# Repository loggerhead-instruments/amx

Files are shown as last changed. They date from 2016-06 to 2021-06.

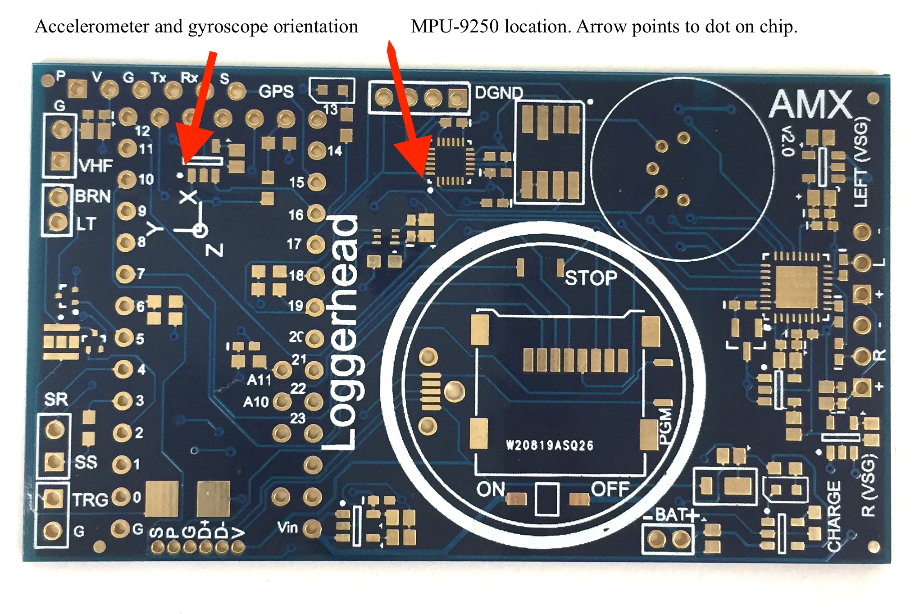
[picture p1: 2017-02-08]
AMXboard_orientation.jpg

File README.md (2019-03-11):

# AMX
AMX is an arduino-compatible audio and motion datalogger board (designed for Teensy 3.x)

More information is at http://loggerhead.com

### Converting AMX to wav and csv files:
- Use AMX2WAV https://github.com/loggerhead-instruments/amx/tree/master/VisualStudio/AMX2WAV/x64/Release

### Files:
- amx: Main control and sensor recording
- cmd.pde: Reads recording settings from a script file
- ISL29125: RGB light sensor interface
- MPU9250: Invensense IMU sensor interface
- wav.h: wav header
- rms: rms calculation

### Sensors:
- Accelerometer, Gyroscope, Magnetometer (MPU9250)
- Pressure/Temperature (MS5803)
- RGB light (ISL29125)
- Burn wire release: controls a FET switch to ground which can be used to corrode a stainless steel wire in seawater

### Software supports:
- duty cycle recording
- display
- button input for recording setup
- writing to microSD

## Updating Firmware

1.	Install Teensyduino from https://www.pjrc.com/teensy/loader.html
2.	Get latest hex file from appropriate repository
	https://github.com/loggerhead-instruments/amx/tree/master/hex
	To save file, right click on the filename and choose 'Save link as'
3.	Connect microUSB cable to small board on device
4.	Run the Teensy Loader program.
5.	From File Menu, select Open HEX File
6.  Turn on power to board
7.	Press the PGM button on the board next to the microSD slot, or from Operation menu, select Program (you may have to turn off automatic mode).

To check whether the firmware has been updated, collect some data, and check the log files for the version date of the firmware.

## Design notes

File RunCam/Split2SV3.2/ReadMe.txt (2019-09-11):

Firmware Upgrade
1. After downloading the firmware, unzip the downloaded file, find the Split2S.BRN file and copy it to the root directory of the microSD card. The firmware name should be confirmed as RCSplit.BRN.
2. Disconnect from the computer, powering the camera via the mobile charger. And then turn on the RUNCAM Split2S with the micro SD card inserted. The camera will automatically update the firmware.
3. Orange light blinks slowly while firmware is upgrading.
4. After 1 minute, the camera will automatically shut down,upgrade has completed.

======================================================================================
New features of RunCam Split2S V3.2.0
1. Fixed bug:The camera does not turn on properly when the camera board is too hot.

======================================================================================
New features of RunCam Split2S V3.1.0
1. Optimize image quality.

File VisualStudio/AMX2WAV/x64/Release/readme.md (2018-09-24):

Downloading AMX.zip

Click on AMX.zip to open new page, then click Download button.
You will have to choose Run Anyway to run.

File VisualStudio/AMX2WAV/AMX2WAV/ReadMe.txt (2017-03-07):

================================================================================
    MICROSOFT FOUNDATION CLASS LIBRARY : AMX2WAV Project Overview
===============================================================================

The application wizard has created this AMX2WAV application for
you.  This application not only demonstrates the basics of using the Microsoft
Foundation Classes but is also a starting point for writing your application.

This file contains a summary of what you will find in each of the files that
make up your AMX2WAV application.

AMX2WAV.vcxproj
    This is the main project file for VC++ projects generated using an application wizard.
    It contains information about the version of Visual C++ that generated the file, and
    information about the platforms, configurations, and project features selected with the
    application wizard.

AMX2WAV.vcxproj.filters
    This is the filters file for VC++ projects generated using an Application Wizard. 
    It contains information about the assciation between the files in your project 
    and the filters. This association is used in the IDE to show grouping of files with
    similar extensions under a specific node (for e.g. ".cpp" files are associated with the
    "Source Files" filter).

AMX2WAV.h
    This is the main header file for the application.  It includes other
    project specific headers (including Resource.h) and declares the
    CAMX2WAVApp application class.

AMX2WAV.cpp
    This is the main application source file that contains the application
    class CAMX2WAVApp.

AMX2WAV.rc
    This is a listing of all of the Microsoft Windows resources that the
    program uses.  It includes the icons, bitmaps, and cursors that are stored
    in the RES subdirectory.  This file can be directly edited in Microsoft
    Visual C++. Your project resources are in 1033.

res\AMX2WAV.ico
    This is an icon file, which is used as the application's icon.  This
    icon is included by the main resource file AMX2WAV.rc.

res\AMX2WAV.rc2
    This file contains resources that are not edited by Microsoft
    Visual C++. You should place all resources not editable by
    the resource editor in this file.

/////////////////////////////////////////////////////////////////////////////

The application wizard creates one dialog class:

AMX2WAVDlg.h, AMX2WAVDlg.cpp - the dialog
    These files contain your CAMX2WAVDlg class.  This class defines
    the behavior of your application's main dialog.  The dialog's template is
    in AMX2WAV.rc, which can be edited in Microsoft Visual C++.

/////////////////////////////////////////////////////////////////////////////

Help Support:

hlp\AMX2WAV.hhp
    This file is a help project file. It contains the data needed to
    compile the help files into a .chm file.

hlp\AMX2WAV.hhc
    This file lists the contents of the help project.

hlp\AMX2WAV.hhk
    This file contains an index of the help topics.

hlp\afxcore.htm
    This file contains the standard help topics for standard MFC
    commands and screen objects. Add your own help topics to this file.

makehtmlhelp.bat
    This file is used by the build system to compile the help files.

hlp\Images\*.gif
    These are bitmap files required by the standard help file topics for
    Microsoft Foundation Class Library standard commands.

/////////////////////////////////////////////////////////////////////////////

Other Features:

ActiveX Controls
    The application includes support to use ActiveX controls.

/////////////////////////////////////////////////////////////////////////////

Other standard files:

StdAfx.h, StdAfx.cpp
    These files are used to build a precompiled header (PCH) file
    named AMX2WAV.pch and a precompiled types file named StdAfx.obj.

Resource.h
    This is the standard header file, which defines new resource IDs.
    Microsoft Visual C++ reads and updates this file.

AMX2WAV.manifest
	Application manifest files are used by Windows XP to describe an applications
	dependency on specific versions of Side-by-Side assemblies. The loader uses this
	information to load the appropriate assembly from the assembly cache or private
	from the application. The Application manifest  maybe included for redistribution
	as an external .manifest file that is installed in the same folder as the application
	executable or it may be included in the executable in the form of a resource.
/////////////////////////////////////////////////////////////////////////////

Other notes:

The application wizard uses "TODO:" to indicate parts of the source code you
should add to or customize.

If your application uses MFC in a shared DLL, you will need
to redistribute the MFC DLLs. If your application is in a language
other than the operating system's locale, you will also have to
redistribute the corresponding localized resources MFC100XXX.DLL.
For more information on both of these topics, please see the section on
redistributing Visual C++ applications in MSDN documentation.

/////////////////////////////////////////////////////////////////////////////

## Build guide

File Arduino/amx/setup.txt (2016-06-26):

// Example setup.txt file

// Set time on power
TM 2016-06-06 12:00:00

// Enable IMU 100 Hz
IM 100.0

// MS Pressure
MP

// RGB light sensor
LS

// Rec duration
RD 30

// Rec interval
RI 30

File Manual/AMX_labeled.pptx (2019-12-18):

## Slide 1

microUSB

Pressure/Temperature

Hydrophone

Tag orientation for heading calculation used by amxEuler.m

East

Light sensor

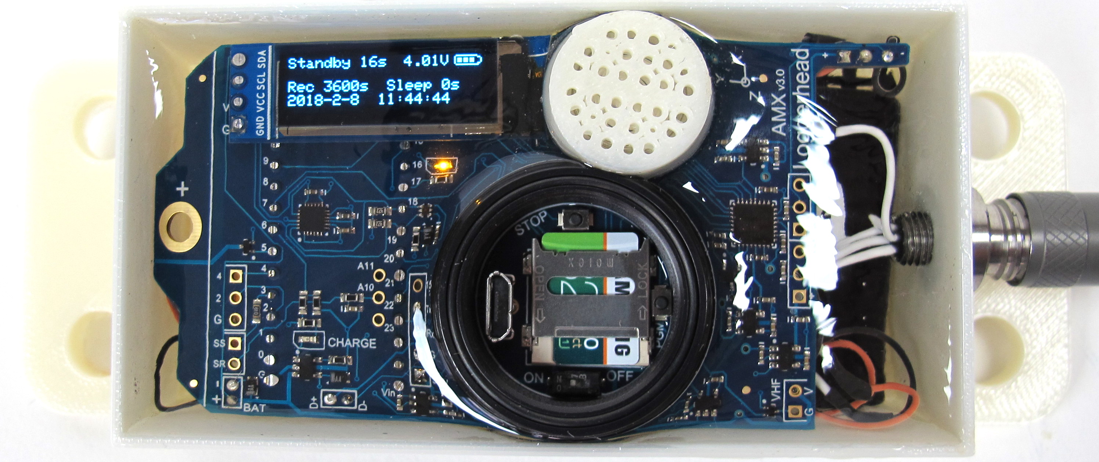
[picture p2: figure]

Motion sensor

North

Charge LED
(turns off when charged)

microUSB

On/Off Switch

microSD card
Slide and flip up to remove

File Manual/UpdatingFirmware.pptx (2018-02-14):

## Updating Firmware

1. Download Teensy loader program from: https://www.pjrc.com/teensy/loader.html
2. Run Teensy Loader
3. File Menu: Open Hex
4. Choose amx.ino.hex (It may say file is too big...ignore)
5. Remove microSD card from AMX
6. Connect microUSB cable to the AMX board
7. Turn AMX power switch to on
8. Short the two pads to force reprogramming. This should cause the firmware to upload.

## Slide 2

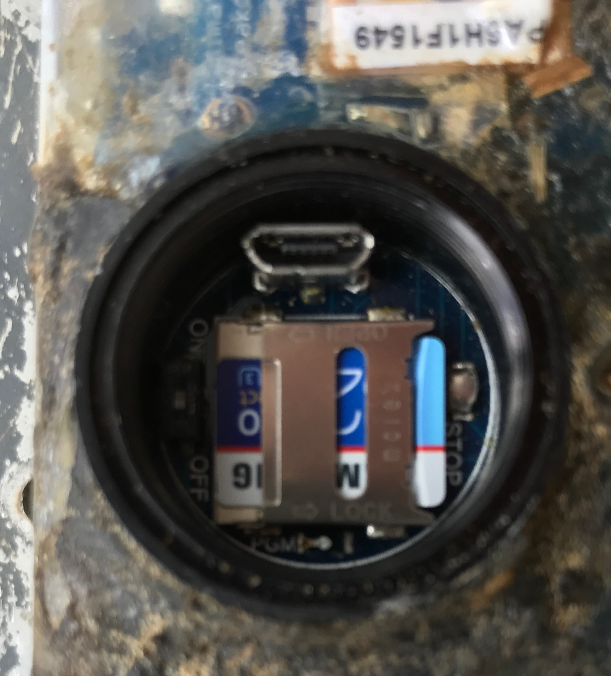
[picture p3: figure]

Connect these two pads with a wire to force reprogramming

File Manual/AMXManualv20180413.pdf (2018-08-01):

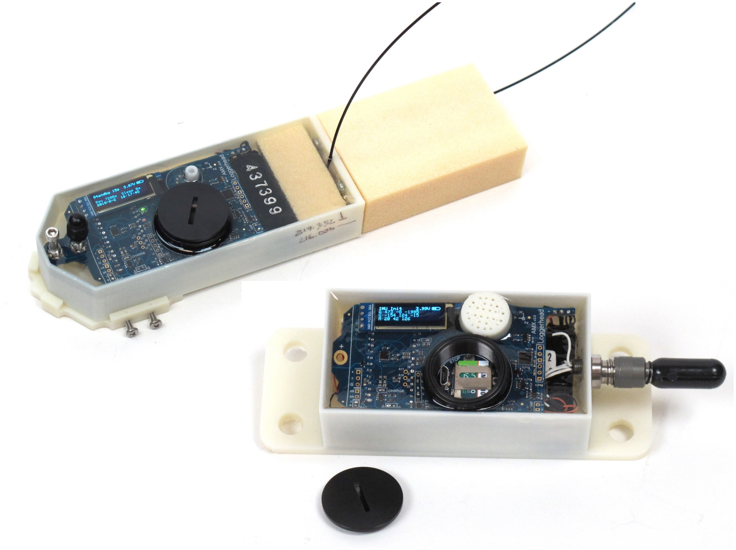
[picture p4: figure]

AMX Manual | 1

# AMX MANUAL

## Audio-Motion Datalogging Tag

Updated 13 April 2018

www.loggerhead.com

## Overview

Hardware

AMX is a multi-sensor datalogger designed for collecting acoustic and motion data from tagged animals and underwater platforms.

Sensors:

- HTI hydrophone: 44.1 kHz
- Accelerometer, Gyroscope, Magnetometer (MPU9250): 100 Hz
- Pressure/Temperature (MS5837 or Keller PA7LD): 1 Hz
- RGB light level (ISL29125): 1 Hz
- Burn wire release: controls a FET switch to ground which can be used to corrode a stainless steel wire in seawater
- Optional camera
- Optional sound playback
- Optional VHF board to aid in recovery

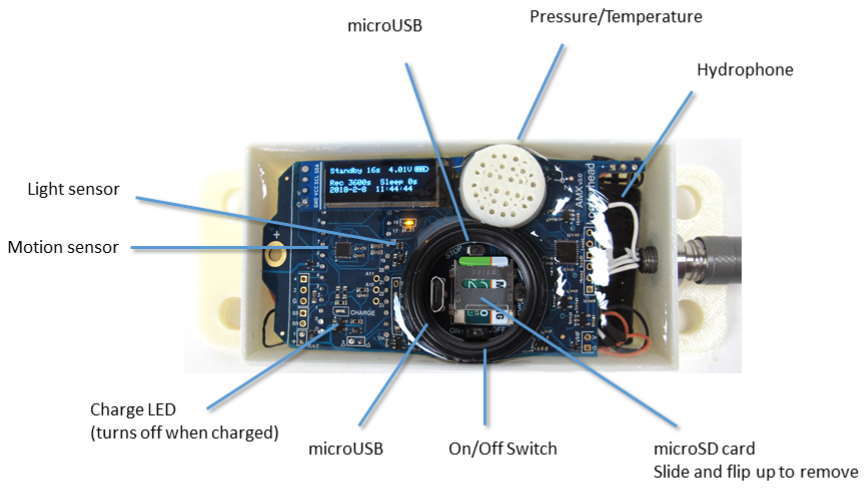
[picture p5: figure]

Software
AMX stores data as .amx binary files. These files can be converted to multi-channel wav files with one for each sensor using AMX2WAV (Windows 10).

https://github.com/loggerhead-instruments/amx/blob/master/AMXsetup.zip

MATLAB code for importing files is available at: https://github.com/loggerhead-instruments/amx/tree/master/MATLAB

All firmware is open source and is available at GitHub: https://github.com/loggerhead-instruments/amx

## Setting up AMX for Deployment

Step 1. Prepare microSD card. Create setup.txt file if setting the time, using the burn wires, or changing default settings. Be sure to safely eject the card before removing from computer.
Step 2. O-rings. Clean and grease o-rings with silicone grease, and insert into the groove on the ring. The o-ring is a 1 x 25 mm 70 Shore A Buna N o-ring. They are McMaster-Carr part number 9262K624.

The o-rings need to be removed and cleaned for each use. If there are nicks in an o-ring DO NOT use it.

Step 3. Turn camera switch on if using camera.
Step 4. Turn on tag power switch and monitor display (see below) during startup.
Step 5. Close lid. Lids should be closed securely using a coin. It should be more than hand-tight.

## Startup Sequence

After powering on AMX the following operations will be performed.

Tag power up sequence | Display | LED pattern
1. Tag turned on | | On for 4 seconds
2. IMU initialization | IMU Init Raw: A(ccelerometer) G(yroscope) M(agnetometer) Calculated: P(itch) R(oll) Y(aw) | Off
3. Light sensor initialization | Light Init R(ed) G(reen) B(lue) | Off
4. Pressure/Temp Sensor Initialization | Pressure (mBar) Depth (m) Temperature (C) | Off
5. Standby to start | Count down Burn date and time *B (if set) Record file duration Sleep duration Current date and time | Solid On
6. Delay Start | If delayed starts | Blink once every 20 seconds
7. Start recording | Turns Off | Blink once per second for 1 hour. After 1 hour the LED will be turned off. The tag will still be recording.

setup.txt Commands
All commands are optional. Default column lists values if no setting in setup.txt file. The sample rates of the pressure and light sensors are fixed.
Command | Function | Default | Example | Setup.txt example
TM | Sets time Time is given as: YY-MM-DD HH:MM:SS If a value is less than 10, it should be written with a leading 0. E.g. 5 should be 05 There must be a space between the DD and HH. | Current time, unless battery exhausted. | Set time to 2017-July-02 04:00:00 when tag powered on | TM 17-07-02 04:00:00
DS | Delay Start (HH:MM) | 00:00 | Delay start for 2 hours | DS 02:00
RD | Record duration (s) | 3600 | Record 600 second files | RD 600
RI | Record interval (s) | 0 | Sleep 240 seconds between files | RI 240
SG | Hydrophone system gain. See table for dB gains associated with different settings. | 4 | Set gain to setting ‘10’, which corresponds to 11.1 dB gain | SG 10
ND | Remove DC from audio. Turning on increases electrical noise | Off | Turn on feature to remove DC from audio | ND
AG | Accelerometer full scale (2, 4, 8, or 16 g) | 16 | Set accelerometer to +/- 8 g full scale | AG 8
IM | IMU sample rate | 100 | Set IMU sample rate to 50 Hz | IM 50

Burn Wire Settings: *Only one burn wire command will be active (the last one in the script).

BW | Burn at YY-MM-DD HH:MM:SS | No burn | Burn at 2017-July-03 20:00:00 | BW 17-07-03 20:00:00
BM | Burn in Minutes from start | No burn | Burn 60 minutes after start | BM 60

Hydrophone Calibration
HC | Hydrophone
sensitivity stored to
file
-180 | Change
hydrophone
sensitivity to -
170 dBV/uPa

HC -170

Playback Commands
Command | Function | Default | Example | Setup.txt example
PF | Number of playback files | 0 | 5 wav files | PF 5
PI | Minimum playback interval (seconds) | 120 | Playbacks separated by at least 500 s | PI 500
PD | Longest file for playback (seconds). Used to power down playback board. | 30 | Longest playback is 15 seconds | PD 15
PT | Playback depth threshold (m). Tag must go deeper than this depth to trigger threshold | 10.0 | Tag must go deeper than 100.0 m before an ascent trigger can trigger playback | PT 100.0
PA | Ascent depth trigger. After exceed depth threshold, the maximum depth is determined. When the tag ascends this amount, playback is triggered | 5.0 | Trigger playback when ascend 20.0 m above the deepest depth | PA 20.0
PR | Reset depth (m). Tag needs to come back above this depth before next playback | 2.0 | Tag must ascend through 5.0 m before another playback can be | PR 5.0

| can happen. | | queued
PM | Max number of playbacks | 20 | Maximum of 10 playbacks | PM 10
SD | Simulate depth profile to test playback. | Off | Turn on simulation of depth (NEVER USE THIS FOR AN ACTUAL DEPLOYMENT) | SD

Debugging
DI
| Print debug information to serial port | Off | Turn on debug information | DI

## Charging

The AMX incorporates rechargeable lithium polymer batteries. Connect the microUSB cable to the AMX and plug into a computer to charge. The red LED will come on to indicate the batteries are charging. The red LED will go out when the batteries are fully charged. It will take approximately 10 hours to fully charge the double-battery version of AMX.

## Power

Tags can be supplied with either 1 or 2 lithium polymer rechargeable batteries (2500 mAh).

Run time for tags without cameras
Run time with 1 battery is approximately 1.5 days.
Run time with 2 batteries is approximately 3.0 days.

Tags with cameras are custom designed to have the needed battery power to achieve user-specified recording durations.

If the battery voltage drops below 3.7 V the camera will be powered down to save power. If the voltage drops below 3.0 V, audio files will stop being recorded.

## Setting Time

The time is set through the setup.txt file. When creating the setup.txt file to set the time, pick a time in the near future. Eject the card, put it in the tag, and then wait until the time you had put in the setup.txt file occurs, and then turn the tag on. The clock will reset to the time in the setup.txt file.

Note that the TM line in setup.txt will be commented out after the time is set, to avoid the time being reset incorrectly if the tag is turned off and on.

## Burn Wire

A burn wire is a corrodible stainless steel wire that can be used to release the AMX from a platform or release suction from suction cups. The recommended wire is from McMaster-Carr (302/304 stainless steel wire 0.01” diameter). https://www.mcmaster.com/ - 6517k61/=17yvpwx

If using suction cups, after attaching the burn wire, coat the base of burn wire where it attaches to the post with nail polish so that it corrodes preferentially at the point of attachment to the suction cups.

The timing of the start of the burn is controlled by a setting in the setup.txt file located on the microSD card in the AMX. Note that the microSD card in the camera is separate, and is only used to store camera data (i.e. don’t put the setup.txt file on the camera card)

There are two ways to set when the burn wire will start, either by specifying a date and time (BW command) or by specifying the number of minutes after the start of recording to start burning (BM command). The format for the two commands is below. Only one of these commands should be used. Pay attention to the exact format of the command. EACH DATE AND TIME VALUE MUST BE TWO CHARACTERS.

BW YY-MM-DD HH:MM:SS
BM minutes

## The BM command is the safest, because it will still work even if the time on the real-time clock is

wrong.

After the burn wire is triggered the VHF beacon will be turned on. When the power gets low, the AMX will go into sleep mode. The green LED will flash 10x once every 2 minutes in sleep mode.

## VHF

If your AMX has the optional VHF, it will turn on based on the depth or the status of the burn wire. If the depth is deeper than 1.0 m, the VHF will turn off. The
VHF will be turned on and stay on after the burn wire is triggered. The VHF signal is very strong, and is picked up as electromagnetic interference on the hydrophone. This is normal, if not annoying.

## Depth Sensors and Maximum Depth

The AMX is equipped with one of two types of pressure sensors, each of which has a maximum depth that it can sustain. If the tag could go deeper than 300 m, the air void where the microSD card is located should be filled with mineral oil. Mineral oil is non-conductive, and will keep the cap from imploding if the tag goes deeper than 300 m.

TE Connectivity (Measurement Specialities)
2 Bar (20 m max depth)
30 Bar (300 m max depth)

Keller
200 Bar (2000 m max depth) Or other sensor as specified.

## HTI Hydrophone Specifications

The AMX uses a hydrophone manufactured by High-Tech Inc. The sensitivity of the hydrophone will be on a specification sheet included with the shipment.

The A/D converter gain can be changed through the setup.txt file. The default is setting 4. The setting can be changed with SG command in setup.txt. The actual setting that was used is stored to the log.txt file.

Setting | Clip Level (peak-peak) | Clip Level (peak) | Gain (dB)
0 | 3.12 | 1.56 | -3.9
1 | 2.63 | 1.315 | -2.4
2 | 2.22 | 1.11 | -0.9
3 | 1.87 | 0.935 | 0.6
4 | 1.58 | 0.79 | 2.0
5 | 1.33 | 0.665 | 3.5
6 | 1.11 | 0.555 | 5.1
7 | 0.94 | 0.47 | 6.6
8 | 0.79 | 0.395 | 8.1
9 | 0.67 | 0.335 | 9.5
10 | 0.56 | 0.28 | 11.1
11 | 0.48 | 0.24 | 12.4
12 | 0.4 | 0.2 | 14.0
13 | 0.34 | 0.17 | 15.4
14 | 0.29 | 0.145 | 16.8
15 | 0.24 | 0.12 | 18.4

## AMX File Conversion Software

The AMX files are binary encoded. AMX2WAV is a Windows 10 software program that will convert the AMX files to a wav file. Each converted wav file stores the data from one of the sensors (e.g. hydrophone audio, 3D IMU, RGB light sensor).

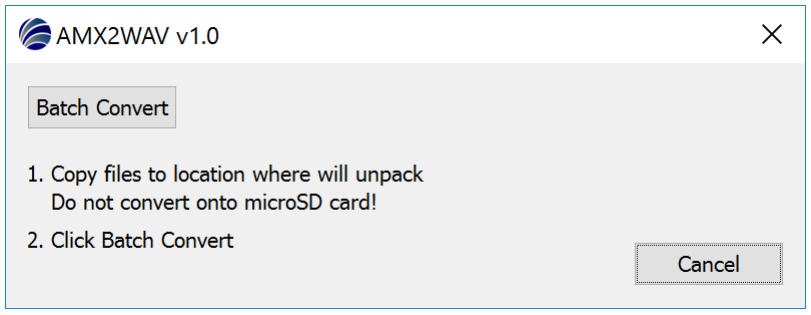
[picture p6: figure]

1. Copy the files from the microSD card to a new location.
2. Click Batch Convert and select a file from the folder where you copied the data to convert.
3. A new folder labeled wav will be created with the converted files.

Playback Operation

The AMX uses the Adafruit Audio FX board with serial interface: https://learn.adafruit.com/adafruit-audio-fx-sound-board/overview

File Configuration
- Files are uploaded to the playback board through a USB connection, and then the drive ejected to make sure they all copied. The copy rate IS VERY SLOW. BE PATIENT!
- Files should be named: T00.wav, T01.wav, T02.wav, T03.wav
- Maximum of 16 MB total for all files
- Files will be triggered in sequence, first 0, then 1, then 2, ….

Setup.txt File
The setup.txt file is placed on the microSD card of the AMX board to control playback operation.
Each command should go on its own line with a space before the value, if the command takes a value.
A double slash // can be used to put in a short comment.

Principles of playback triggering
1. A depth threshold (PT) must be exceeded to prime a playback.
2. Once the depth threshold is exceeded, a playback will occur when the depth goes shallower than the ascent depth trigger (PA).
3. For another playback to occur, the following must be satisfied:
1. the tag went shallower than the reset depth (PR). This is to prevent multiple playbacks if the animal goes up and down around the ascent depth trigger.
2. at least x seconds (PI) must have elapsed since the last playback

Testing Settings
The SD command in setup.txt may be used to have the tag cycle through simulated depths.

The simulated profile is hard coded here as one depth value per minute. The value used will correspond to the real-time clock minute.
float depthProfile[] = {0.0, 12.0, 1.0, 12.0, 4.0, 3.0, 10.0, 20.0, 50.0, 10.0, 0.0, 1.0, 40.0, 11.0, 5.0, 2.0, 0.0, 50.0, 2.0, 4.0,0.0, 12.0, 1.0, 20.0, 4.0, 3.0, 10.0, 20.0, 50.0, 10.0, 0.0, 1.0, 12.0, 11.0, 5.0, 2.0, 0.0, 60.0, 2.0, 4.0, 0.0, 12.0, 1.0, 20.0, 4.0, 3.0, 10.0, 20.0, 50.0, 10.0, 0.0, 1.0, 12.0, 11.0, 5.0, 2.0, 0.0, 70.0, 2.0, 4.0};

A custom depth profile can be loaded in a depth.txt file. The depth.txt file should list one depth per line. A maximum of 60 depths can be listed in the depth.txt file.

The simulated depth is NOT stored in the recorded files. It is only used to trigger playbacks.

Example of playbacks on a depth profile
Blue line: Water surface
Green line: Reset depth
Red line: Ascent trigger (when going shallower than this line a playback may be triggered)
Orange line: Depth threshold (must go deeper than this depth to prime ascent trigger)

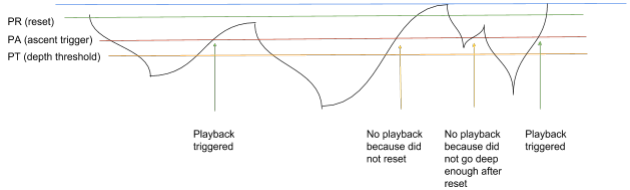
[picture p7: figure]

Example setup.txt file for testing simulated depths

// Simulate playback
// Number files
PF 4
// Minimum time between files PI 600
// Longest file
PD 15
// Depth threshold
PT 40
// Ascent threshold
PA 30
// Reset depth
PR 5
// Simulate depth profile
SD
// Debug info
DI

## Appendix I

Formatting SD card with EaseUS Partition Master for Cards Larger than 32 GB

### 32 GB cards can be formatted as FAT32 in Windows with standard re-

formatting. New 32 GB cards will come formatted as FAT32 (you don’t need to do anything).

Cards larger than 32 GB can not be formatted with the FAT32 file system with the regular windows formatting tools. Cards shipped from Loggerhead have been formatted as FAT32. The exFAT file system will not work with the DSG boards. These larger cards can be formatted with EaseUS Partition Master, which has a free personal edition available.
http://www.partition-tool.com/personal.htm

Run EaseUS Partition Master

1. Select drive with SD card.
2. Click on Format Partition on left.

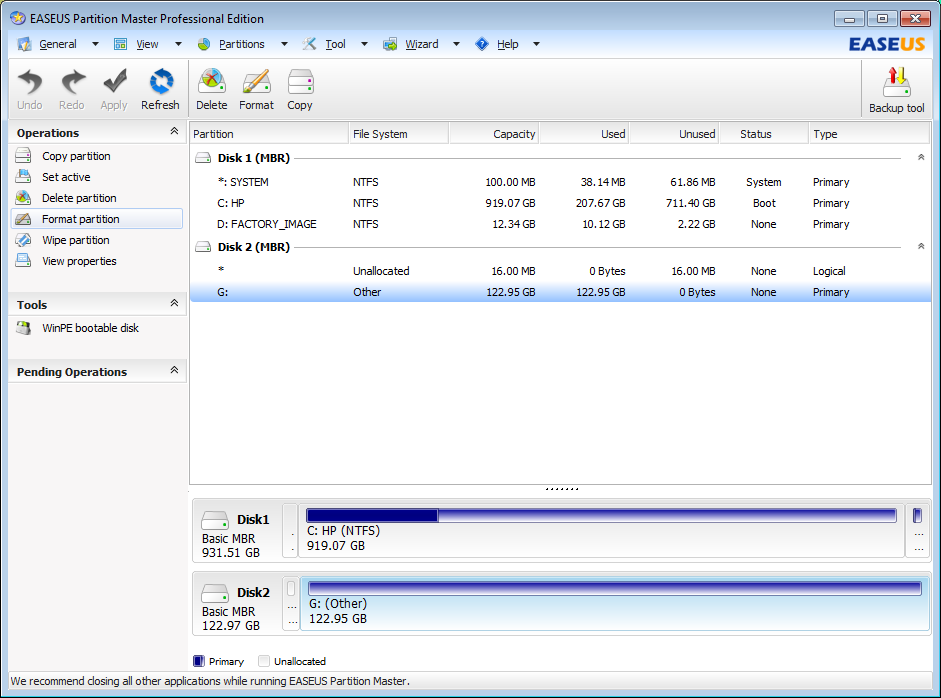
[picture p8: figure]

3. Make sure File System is FAT32. Click OK.

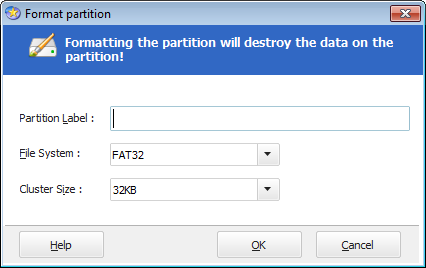
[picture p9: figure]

4. Click Apply on the toolbar. Then click Yes.

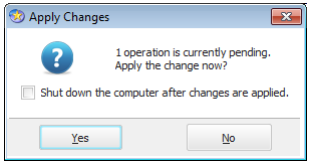
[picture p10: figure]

You should see this screen. When it is done you can close EaseUS.

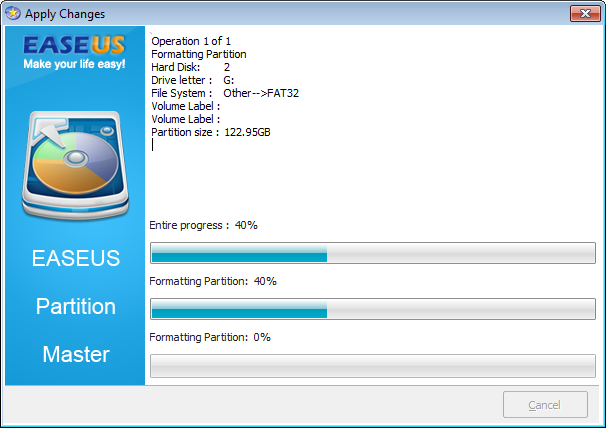
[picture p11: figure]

Appendix II

Revision History

Date | Changes
2018-13-2018 | Added Delay Start (DS) Version format in AMX changed to YYYYMMDD

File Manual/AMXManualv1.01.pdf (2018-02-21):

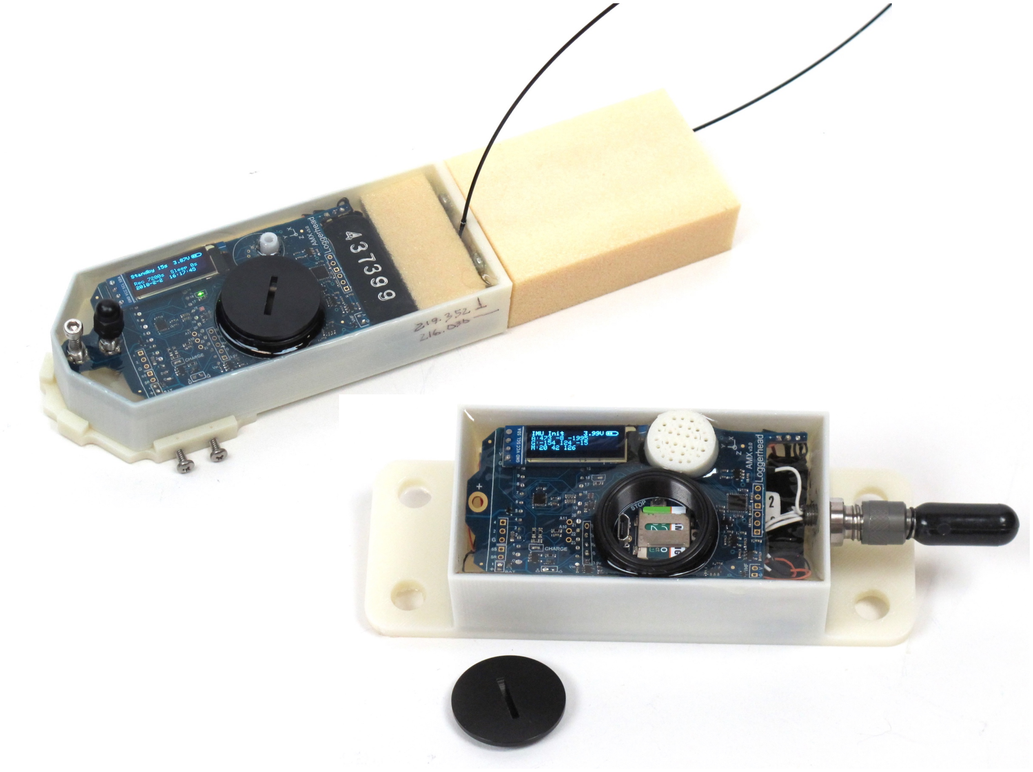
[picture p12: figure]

AMX Manual | 1

# AMX MANUAL

## Audio-Motion Datalogging Tag

Manual v1.0
Updated 8 February 2018

www.loggerhead.com

## Overview

Hardware

AMX is a multi-sensor datalogger designed for collecting acoustic and motion data from tagged animals and underwater platforms.

Sensors:

- HTI hydrophone: 44.1 kHz
- Accelerometer, Gyroscope, Magnetometer (MPU9250): 100 Hz
- Pressure/Temperature (MS5837 or Keller PA7LD): 1 Hz
- RGB light level (ISL29125): 1 Hz
- Burn wire release: controls a FET switch to ground which can be used to corrode a stainless steel wire in seawater
- Optional camera
- Optional sound playback
- Optional VHF board to aid in recovery


Software
AMX stores data as .amx binary files. These files can be converted to multi-channel wav files with one for each sensor using AMX2WAV (Windows 10).

https://github.com/loggerhead-instruments/amx/blob/master/AMXsetup.zip

MATLAB code for importing files is available at: https://github.com/loggerhead-instruments/amx/tree/master/MATLAB

All firmware is open source and is available at GitHub: https://github.com/loggerhead-instruments/amx

## Setting up AMX for Deployment

Step 1. Prepare microSD card. Create setup.txt file if setting the time, using the burn wires, or changing default settings. Be sure to safely eject the card before removing from computer.
Step 2. O-rings. Clean and grease o-rings with silicone grease, and insert into the groove on the ring. The o-ring is a 1 x 25 mm 70 Shore A Buna N o-ring. They are McMaster-Carr part number 9262K624.

The o-rings need to be removed and cleaned for each use. If there are nicks in an o-ring DO NOT use it.

Step 3. Turn camera switch on if using camera.
Step 4. Turn on tag power switch and monitor display (see below) during startup.
Step 5. Close lid. Lids should be closed securely using a coin. It should be more than hand-tight.

## Startup Sequence

After powering on AMX the following operations will be performed.

Tag power up sequence | Display | LED pattern
1. Tag turned on | | On for 4 seconds
2. IMU initialization | IMU Init Raw: A(ccelerometer) G(yroscope) M(agnetometer) Calculated: P(itch) R(oll) Y(aw) | Off
3. Light sensor initialization | Light Init R(ed) G(reen) B(lue) | Off
4. Pressure/Temp Sensor Initialization | Pressure (mBar) Depth (m) Temperature (C) | Off
5. Standby to start | Count down Burn date and time *B (if set) Record file duration Sleep duration Current date and time | Solid On
6. Start recording | Turns Off | Blink for 1 hour. After 1 hour the LED will be turned off. The tag will still be recording.

setup.txt Commands
All commands are optional. Default column lists values if no setting in setup.txt file. The sample rates of the pressure and light sensors are fixed.
Command | Function | Default | Example | Setup.txt example
TM | Sets time Time is given as: YY-MM-DD HH:MM:SS If a value is less than 10, it should be written with a leading 0. E.g. 5 should be 05 There must be a space between the DD and HH. | Current time, unless battery exhausted. | Set time to 2017-July-02 04:00:00 when tag powered on | TM 17-07-02 04:00:00
RD | Record duration (s) | 3600 | Record 600 second files | RD 600
RI | Record interval (s) | 0 | Sleep 240 seconds between files | RI 240
SG | Hydrophone system gain. See table for dB gains associated with different settings. | 4 | Set gain to setting ‘10’, which corresponds to 11.1 dB gain | SG 10
ND | Remove DC from audio. Turning on increases electrical noise | Off | Turn on feature to remove DC from audio | ND
AG | Accelerometer full scale (2, 4, 8, or 16 g) | 16 | Set accelerometer to +/- 8 g full scale | AG 8
IM | IMU sample rate | 100 | Set IMU sample rate to 50 Hz | IM 50

Burn Wire Settings: *Only one burn wire command will be active (the last one in the script).

BW | Burn at YY-MM-DD HH:MM:SS | No burn | Burn at 2017-July-03 20:00:00 | BW 17-07-03 20:00:00
BM | Burn in Minutes from start | No burn | Burn 60 minutes after start | BM 60

Hydrophone Calibration
HC | Hydrophone
sensitivity stored to
file
-180 | Change
hydrophone
sensitivity to -
170 dBV/uPa

HC -170

Playback Commands

PF | Number of playback files | 0 | 5 wav files | PF 5
PI | Minimum playback interval (seconds) | 120 | Playbacks separated by at least 500 s | PI 500
PD | Longest file for playback (seconds). Used to power down playback board. | 30 | Longest playback is 15 seconds | PD 15
PT | Playback depth threshold (m). Tag must go deeper than this depth to trigger threshold | 10.0 | Tag must go deeper than 100.0 m before an ascent trigger can trigger playback | PT 100.0
PA | Ascent depth trigger. After exceed depth threshold, must ascend this amount to trigger playback | 5.0 | Trigger playback when ascend through 20.0 m | PA 20.0
PR | Reset depth (m). Tag needs to come back above this depth before next playback can happen. | 2.0 | Tag must ascend through 5.0 m before another playback can be queued | PR 5.0
PM | Max number of playbacks | 20 | Maximum of 10 playbacks | PM 10

SD | Simulate depth profile
to test playback.
Off | Turn on
simulation of
depth (NEVER
USE THIS FOR
AN ACTUAL
DEPLOYMENT)

SD

Debugging
DI
| Print debug information to serial port | Off | Turn on debug information | DI

## Charging

The AMX incorporates rechargeable lithium polymer batteries. Connect the microUSB cable to the AMX and plug into a computer to charge. The red LED will come on to indicate the batteries are charging. The red LED will go out when the batteries are fully charged. It will take approximately 10 hours to fully charge the double-battery version of AMX.

## Power

Tags can be supplied with either 1 or 2 lithium polymer rechargeable batteries (2500 mAh).

Run time for tags without cameras
Run time with 1 battery is approximately 1.5 days.
Run time with 2 batteries is approximately 3.0 days.

Tags with cameras are custom designed to have the needed battery power to achieve user-specified recording durations.

If the battery voltage drops below 3.7 V the camera will be powered down to save power. If the voltage drops below 3.0 V, audio files will stop being recorded.

## Setting Time

The time is set through the setup.txt file. When creating the setup.txt file to set the time, pick a time in the near future. Eject the card, put it in the tag, and then wait until the time you had put in the setup.txt file occurs, and then turn the tag on. The clock will reset to the time in the setup.txt file.

Note that the TM line in setup.txt will be commented out after the time is set, to avoid the time being reset incorrectly if the tag is turned off and on.

## Burn Wire

A burn wire is a corrodible stainless steel wire that can be used to release the AMX from a platform or release suction from suction cups. The recommended wire is from McMaster-Carr (302/304 stainless steel wire 0.01” diameter). https://www.mcmaster.com/ - 6517k61/=17yvpwx

If using suction cups, after attaching the burn wire, coat the base of burn wire where it attaches to the post with nail polish so that it corrodes preferentially at the point of attachment to the suction cups.

The timing of the start of the burn is controlled by a setting in the setup.txt file located on the microSD card in the AMX. Note that the microSD card in the camera is separate, and is only used to store camera data (i.e. don’t put the setup.txt file on the camera card)

There are two ways to set when the burn wire will start, either by specifying a date and time (BW command) or by specifying the number of minutes after the start of recording to start burning (BM command). The format for the two commands is below. Only one of these commands should be used. Pay attention to the exact format of the command. EACH DATE AND TIME VALUE MUST BE TWO CHARACTERS.

BW YY-MM-DD HH:MM:SS
BM minutes

## The BM command is the safest, because it will still work even if the time on the real-time clock is

wrong.

After the burn wire is triggered the VHF beacon will be turned on. When the power gets low, the AMX will go into sleep mode. The green LED will flash 10x once every 2 minutes in sleep mode.

## VHF

If your AMX has the optional VHF, it will turn on based on the depth or the status of the burn wire. If the depth is deeper than 1.0 m, the VHF will turn off. The
VHF will be turned on and stay on after the burn wire is triggered. The VHF signal is very strong, and is picked up as electromagnetic interference on the hydrophone. This is normal, if not annoying.

## Depth Sensors and Maximum Depth

The AMX is equipped with one of two types of pressure sensors, each of which has a maximum depth that it can sustain. If the tag could go deeper than 300 m, the air void where the microSD card is located should be filled with mineral oil. Mineral oil is non-conductive, and will keep the cap from imploding if the tag goes deeper than 300 m.

TE Connectivity (Measurement Specialities)
2 Bar (20 m max depth)
30 Bar (300 m max depth)

Keller
200 Bar (2000 m max depth) Or other sensor as specified.

## HTI Hydrophone Specifications

The AMX uses a hydrophone manufactured by High-Tech Inc. The sensitivity of the hydrophone will be on a specification sheet included with the shipment.

The A/D converter gain can be changed through the setup.txt file. The default is setting 4. The setting can be changed with SG command in setup.txt. The actual setting that was used is stored to the log.txt file.

Setting | Clip Level (peak-peak) | Clip Level (peak) | Gain (dB)
0 | 3.12 | 1.56 | -3.9
1 | 2.63 | 1.315 | -2.4
2 | 2.22 | 1.11 | -0.9
3 | 1.87 | 0.935 | 0.6
4 | 1.58 | 0.79 | 2.0
5 | 1.33 | 0.665 | 3.5
6 | 1.11 | 0.555 | 5.1
7 | 0.94 | 0.47 | 6.6
8 | 0.79 | 0.395 | 8.1
9 | 0.67 | 0.335 | 9.5
10 | 0.56 | 0.28 | 11.1
11 | 0.48 | 0.24 | 12.4
12 | 0.4 | 0.2 | 14.0
13 | 0.34 | 0.17 | 15.4
14 | 0.29 | 0.145 | 16.8
15 | 0.24 | 0.12 | 18.4

## AMX File Conversion Software

The AMX files are binary encoded. AMX2WAV is a Windows 10 software program that will convert the AMX files to a wav file. Each converted wav file stores the data from one of the sensors (e.g. hydrophone audio, 3D IMU, RGB light sensor).

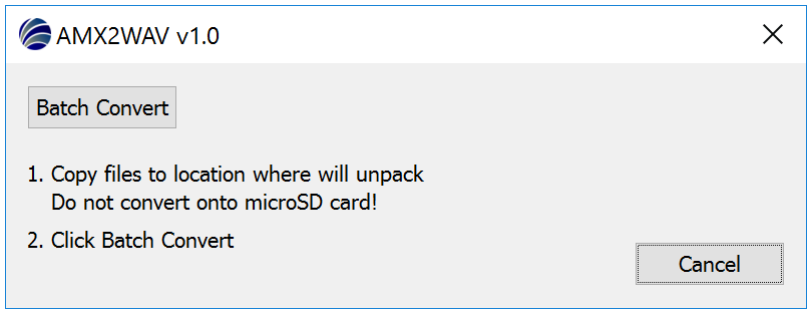
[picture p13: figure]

1. Copy the files from the microSD card to a new location.
2. Click Batch Convert and select a file from the folder where you copied the data to convert.
3. A new folder labeled wav will be created with the converted files.

Playback Operation

The AMX uses the Adafruit Audio FX board with serial interface: https://learn.adafruit.com/adafruit-audio-fx-sound-board/overview

File Configuration
- Files are uploaded to the playback board through a USB connection, and then the drive ejected to make sure they all copied. The copy rate IS VERY SLOW. BE PATIENT!
- Files should be named: T00.wav, T01.wav, T02.wav, T03.wav
- Maximum of 16 MB total for all files
- Files will be triggered in sequence, first 0, then 1, then 2, ….

Setup.txt File
The setup.txt file is placed on the microSD card of the AMX board to control playback operation.
Each command should go on its own line with a space before the value, if the command takes a value.
A double slash // can be used to put in a short comment.

Principles of playback triggering
1. A depth threshold (PT) must be exceeded to prime a playback.
2. Once the depth threshold is exceeded, a playback will occur when the depth goes shallower than the ascent depth trigger (PA).
3. For another playback to occur, the following must be satisfied:
1. the tag went shallower than the reset depth (PR). This is to prevent multiple playbacks if the animal goes up and down around the ascent depth trigger.
2. at least x seconds (PI) must have elapsed since the last playback

Testing Settings
The SD command in setup.txt may be used to have the tag cycle through simulated depths.

The simulated profile is hard coded here as one depth value per minute. The value used will correspond to the real-time clock minute.
float depthProfile[] = {0.0, 12.0, 1.0, 12.0, 4.0, 3.0, 10.0, 20.0, 50.0, 10.0, 0.0, 1.0, 40.0, 11.0, 5.0, 2.0, 0.0, 50.0, 2.0, 4.0,0.0, 12.0, 1.0, 20.0, 4.0, 3.0, 10.0, 20.0, 50.0, 10.0, 0.0, 1.0, 12.0, 11.0, 5.0, 2.0, 0.0, 60.0, 2.0, 4.0, 0.0, 12.0, 1.0, 20.0, 4.0, 3.0, 10.0, 20.0, 50.0, 10.0, 0.0, 1.0, 12.0, 11.0, 5.0, 2.0, 0.0, 70.0, 2.0, 4.0};

A custom depth profile can be loaded in a depth.txt file. The depth.txt file should list one depth per line. A maximum of 60 depths can be listed in the depth.txt file.

The simulated depth is NOT stored in the recorded files. It is only used to trigger playbacks.

Example of playbacks on a depth profile
Blue line: Water surface
Green line: Reset depth
Red line: Ascent trigger (when going shallower than this line a playback may be triggered)
Orange line: Depth threshold (must go deeper than this depth to prime ascent trigger)

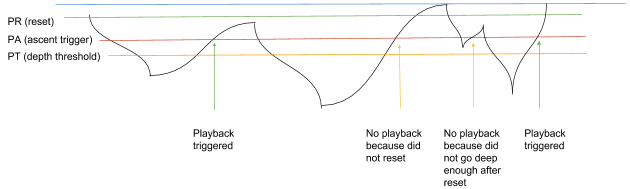
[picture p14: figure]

Example setup.txt file for testing simulated depths

// Simulate playback
// Number files
PF 4
// Minimum time between files PI 600
// Longest file
PD 15
// Depth threshold
PT 40
// Ascent threshold
PA 30
// Reset depth
PR 5
// Simulate depth profile
SD
// Debug info
DI

## Appendix I

Formatting SD card with EaseUS Partition Master for Cards Larger than 32 GB

### 32 GB cards can be formatted as FAT32 in Windows with standard re-

formatting. New 32 GB cards will come formatted as FAT32 (you don’t need to do anything).

Cards larger than 32 GB can not be formatted with the FAT32 file system with the regular windows formatting tools. Cards shipped from Loggerhead have been formatted as FAT32. The exFAT file system will not work with the DSG boards. These larger cards can be formatted with EaseUS Partition Master, which has a free personal edition available.
http://www.partition-tool.com/personal.htm

Run EaseUS Partition Master

1. Select drive with SD card.
2. Click on Format Partition on left.


3. Make sure File System is FAT32. Click OK.

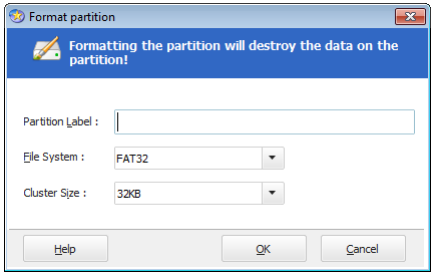
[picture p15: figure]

4. Click Apply on the toolbar. Then click Yes.

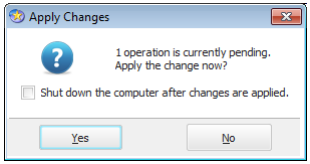
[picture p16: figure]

You should see this screen. When it is done you can close EaseUS.


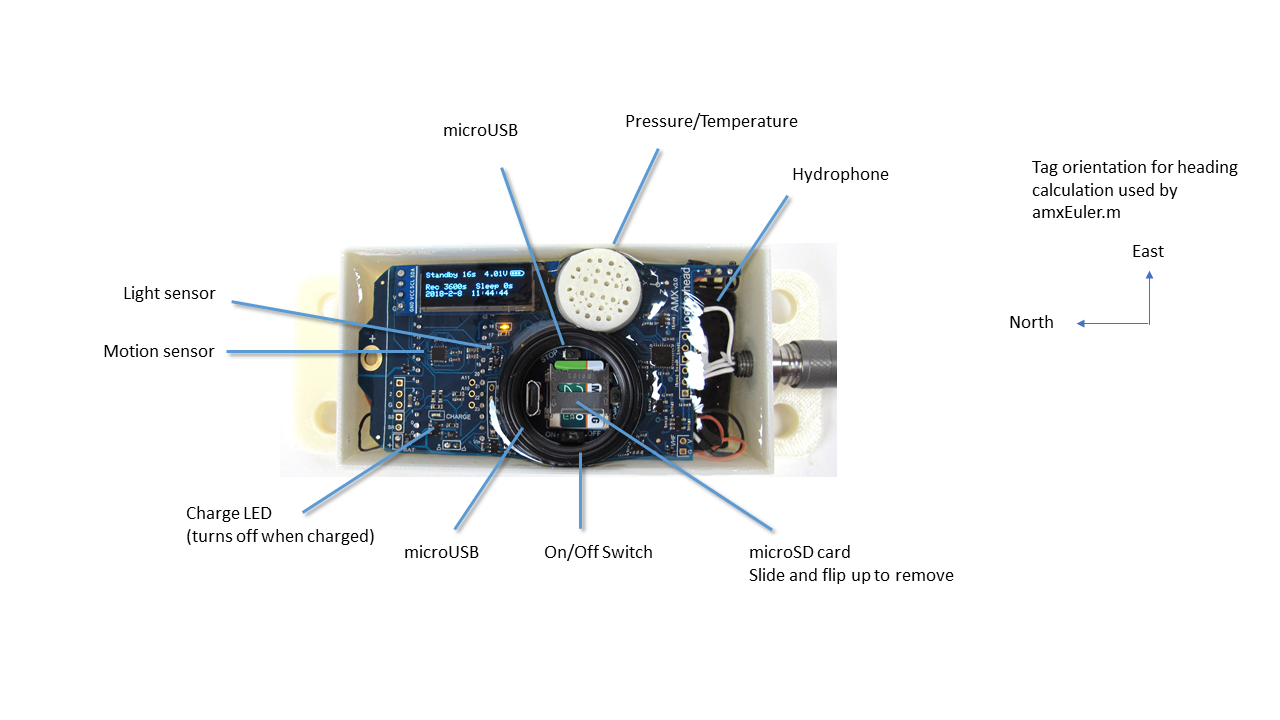
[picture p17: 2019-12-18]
Manual/AMX_labeled.png

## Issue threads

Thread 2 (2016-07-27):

keller pressure sensor first two reads bad

davidallenmann, 2016-07-27:
On initialize...make a few reads so first value is OK

davidallenmann, 2018-01-31:
fixed

Closed 2018-01-31.

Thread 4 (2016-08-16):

reset audio chip at start to avoid lockup

davidallenmann, 2016-08-16:
Have seen situations where audio chip won't be recognized at startup.  Need way to reset it around line 280

davidallenmann, 2016-09-11:
using our own AudioEnable code.  Have not seen this bug on our own boards.  Only on Teensy audio board

Closed 2016-09-11.

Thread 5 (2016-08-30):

use light sensor to control whether screen/LEDs illuminated

davidallenmann, 2016-08-30:

davidallenmann, 2016-09-11:
not going to implement....one more thing to fail....simple recorder won't have light sensor

Closed 2016-09-11.

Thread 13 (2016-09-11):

ContinueRecording: should queue be processed until <2

davidallenmann, 2016-09-11:
should this be while?

Could it mess up timing of recording other sensors?
```
  if (queue1.available() >= 2) {
    byte buffer[512];
    // Fetch 2 blocks from the audio library and copy
    // into a 512 byte buffer.  The Arduino SD library
    // is most efficient when full 512 byte sector size
    // writes are used.
    //digitalWrite(ledGreen, HIGH);
    memcpy(buffer, queue1.readBuffer(), 256);
    queue1.freeBuffer();
    memcpy(buffer+256, queue1.readBuffer(), 256);
    queue1.freeBuffer();
    if (fileType==0){
      frec.write(buffer, 512); //audio to .wav file
    }
    else{
      frec.write((uint8_t *)&sidRec[0],sizeof(SID_REC)); //audio to .amx file
      frec.write(buffer, 512);
    }
```

davidallenmann, 2016-09-13:
seems to be working OK, so leaving for now.

Closed 2016-09-13.

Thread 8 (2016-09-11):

samsung Pro 32 GB file does not open after sleep

davidallenmann, 2016-09-11:
Testing with AMX board with DPST switch on microSD.

davidallenmann, 2016-09-12:
issue is related to microSD switch circuit....does not fail on older board that does not have these....
so, leave off acoustic datalogger version....will need to do some USB based download for tag version

davidallenmann, 2016-09-14:
maybe problem is VCC is going through CMOS....hard wired VCC to board and testing

davidallenmann, 2016-09-14:
powering card directly fixes problem...so was probably a current limitation problem through DPST CMOS switch

Closed 2016-09-14.

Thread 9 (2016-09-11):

queue.begin does not start recording after wake from hibernate

davidallenmann, 2016-09-11:
Testing with Samsung 8 GB card.
About 1/10 files.
Record 10 s. Sleep 50 s.

davidallenmann, 2016-09-11:
queue.begin() is getting called.  Does not appear to be crashing code.
Happens on about 3rd file.

davidallenmann, 2016-09-11:
could be I2S not starting, or audio chip not initializing properly

davidallenmann, 2016-09-11:
or audio memory overflow

davidallenmann, 2016-09-11:
it is not crashing code...test code to look at clock on display keeps ticking

davidallenmann, 2016-09-11:
Test with sleep code commented out: do not have problem in about 20 files

davidallenmann, 2016-09-11:
sleep only commented (power save features ON then OFF still in): do not have problem after 20 files

davidallenmann, 2016-09-11:
Snooze.sleep() instead of Snooze.hibernate(): does not wake up

davidallenmann, 2016-09-11:
hiberate VLLS0 : reset program

davidallenmann, 2016-09-11:
Snooze.deepSleep(): get problem of queue not starting on second file

davidallenmann, 2016-09-12:
This should not matter, but testing with previous version of board without uSD digital switch

davidallenmann, 2016-09-12:
testing AudioNoInterrupts(); before hibernate and AudioInterrupts(); after wake

davidallenmann, 2016-09-12:
when fails: BCLK and MCLK are running properly.  No signal on LRCLK or RX.

davidallenmann, 2016-09-12:
testing with original SGTL5000 enable code (but still going into low power mode for the chip while sleeping)

davidallenmann, 2016-09-12:
updated teensyduino and https://github.com/duff2013/Snooze_V6_Beta
Hibernate still has problem of queue not starting

davidallenmann, 2016-09-12:
deepSleep failed after two (with new beta library)
sleep did not fail after ~20 recordings; will let it run longer

davidallenmann, 2016-09-13:
new beta sleep seems to work.  power draw 2.8 mA during sleep.

davidallenmann, 2016-09-13:
hibernate fails also with:
```
SnoozeAlarm alarm;
SnoozeAudio snooze_audio;
SnoozeBlock config_teensy32(snooze_audio, alarm);
```

davidallenmann, 2016-09-13:
trying hibernate, but not powering down audio chip (i know i tried this before...but just checking)

davidallenmann, 2017-03-06:
seems to be working with Snooze.sleep(config_teensy32);

Closed 2017-03-06.

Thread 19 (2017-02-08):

Reported battery voltage is too low

davidallenmann, 2017-02-08:
Getting 3.6 when battery fully charged (should be more like 4.2)

davidallenmann, 2017-03-05:
adjusted voltage sensitivity

Closed 2017-03-05.

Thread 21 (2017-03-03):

if IMU FIFO overruns, can get multi-byte shift---if happens, reset FIFO and start record over

davidallenmann, 2017-03-03:

Closed 2017-03-05.

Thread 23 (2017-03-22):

RTC stops ticking during snooze

davidallenmann, 2017-03-22:
possibly i2c_t3 library interfering?
Works on Snap

davidallenmann, 2017-03-22:
may be related to https://github.com/duff2013/Snooze/issues/5

davidallenmann, 2017-03-22:
adding setSyncProvider at beginning as in Snap did not fix

Closed 2017-03-22.

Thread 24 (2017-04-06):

MPU9250 says magnetometer is little endian, check if correct

davidallenmann, 2017-04-06:

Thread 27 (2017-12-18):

Stop button moved to Pin 20

davidallenmann, 2017-12-18:
Rev 3 PCB change

davidallenmann, 2018-01-31:
fixed

Closed 2018-01-31.

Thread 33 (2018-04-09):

depth calculation for 30 bar sensor seems off

davidallenmann, 2018-04-09:
When startup shows depth close to 0.0 m.
But, during running shows depth around 8 m.

200 bar Keller is working correctly.

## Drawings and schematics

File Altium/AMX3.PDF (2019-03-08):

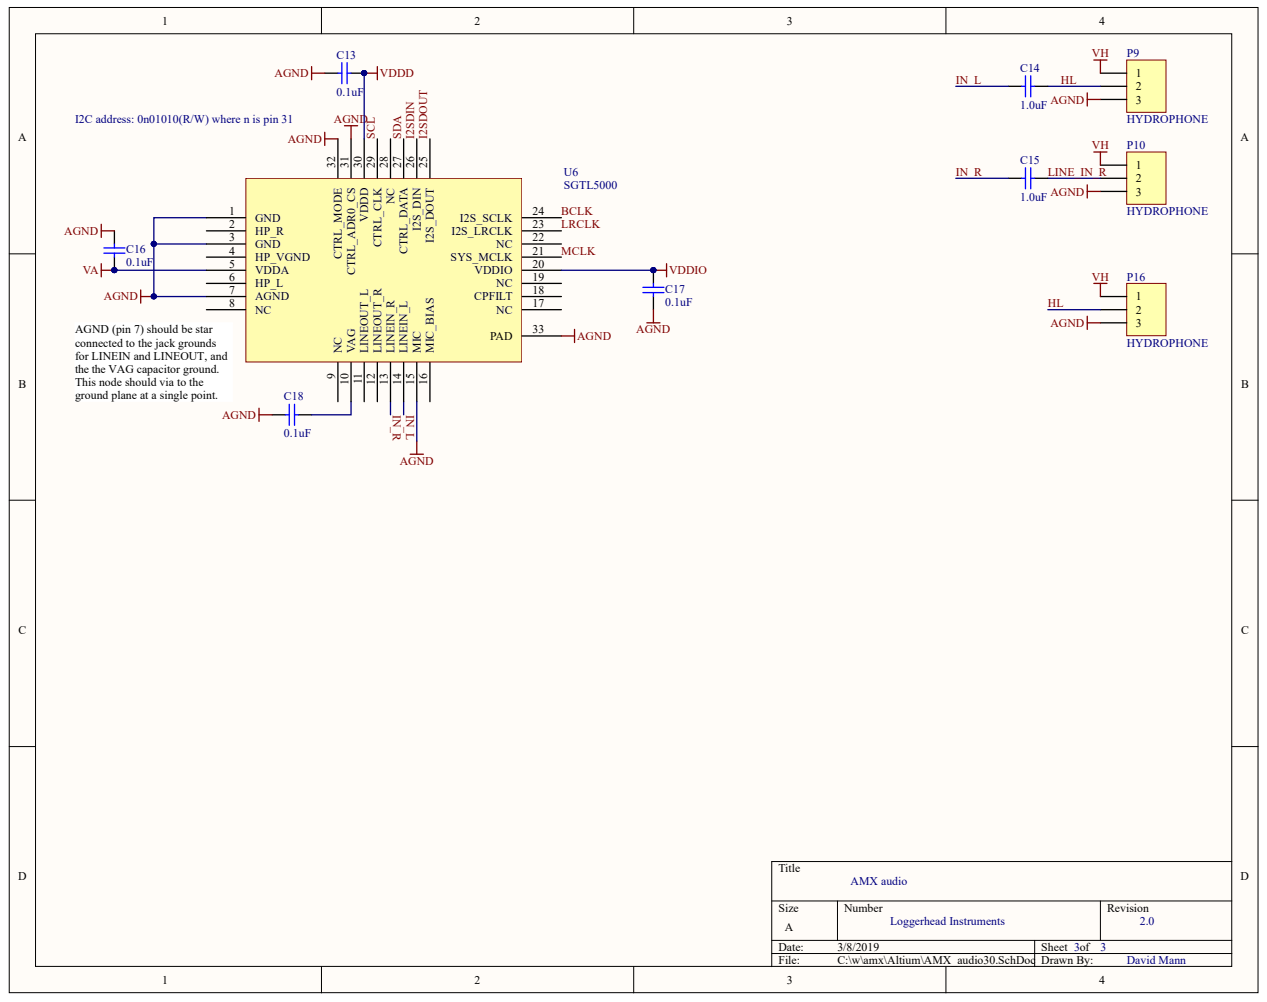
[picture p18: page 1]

AGND (pin 7) should be star
connected to the jack grounds
for LINEIN and LINEOUT, and
the the VAG capacitor ground.
This node should via to the
ground plane at a single point.

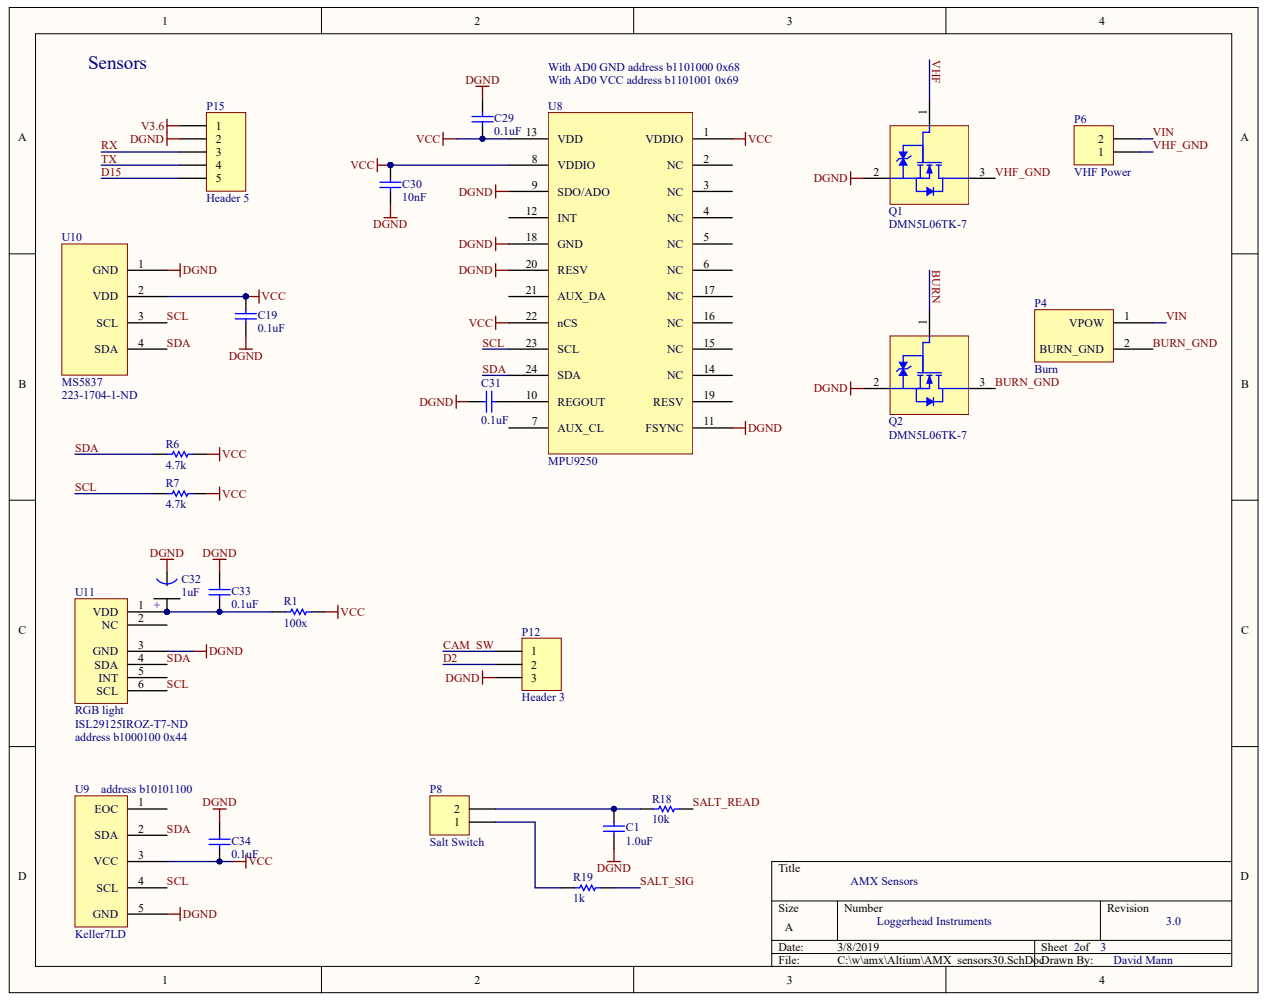
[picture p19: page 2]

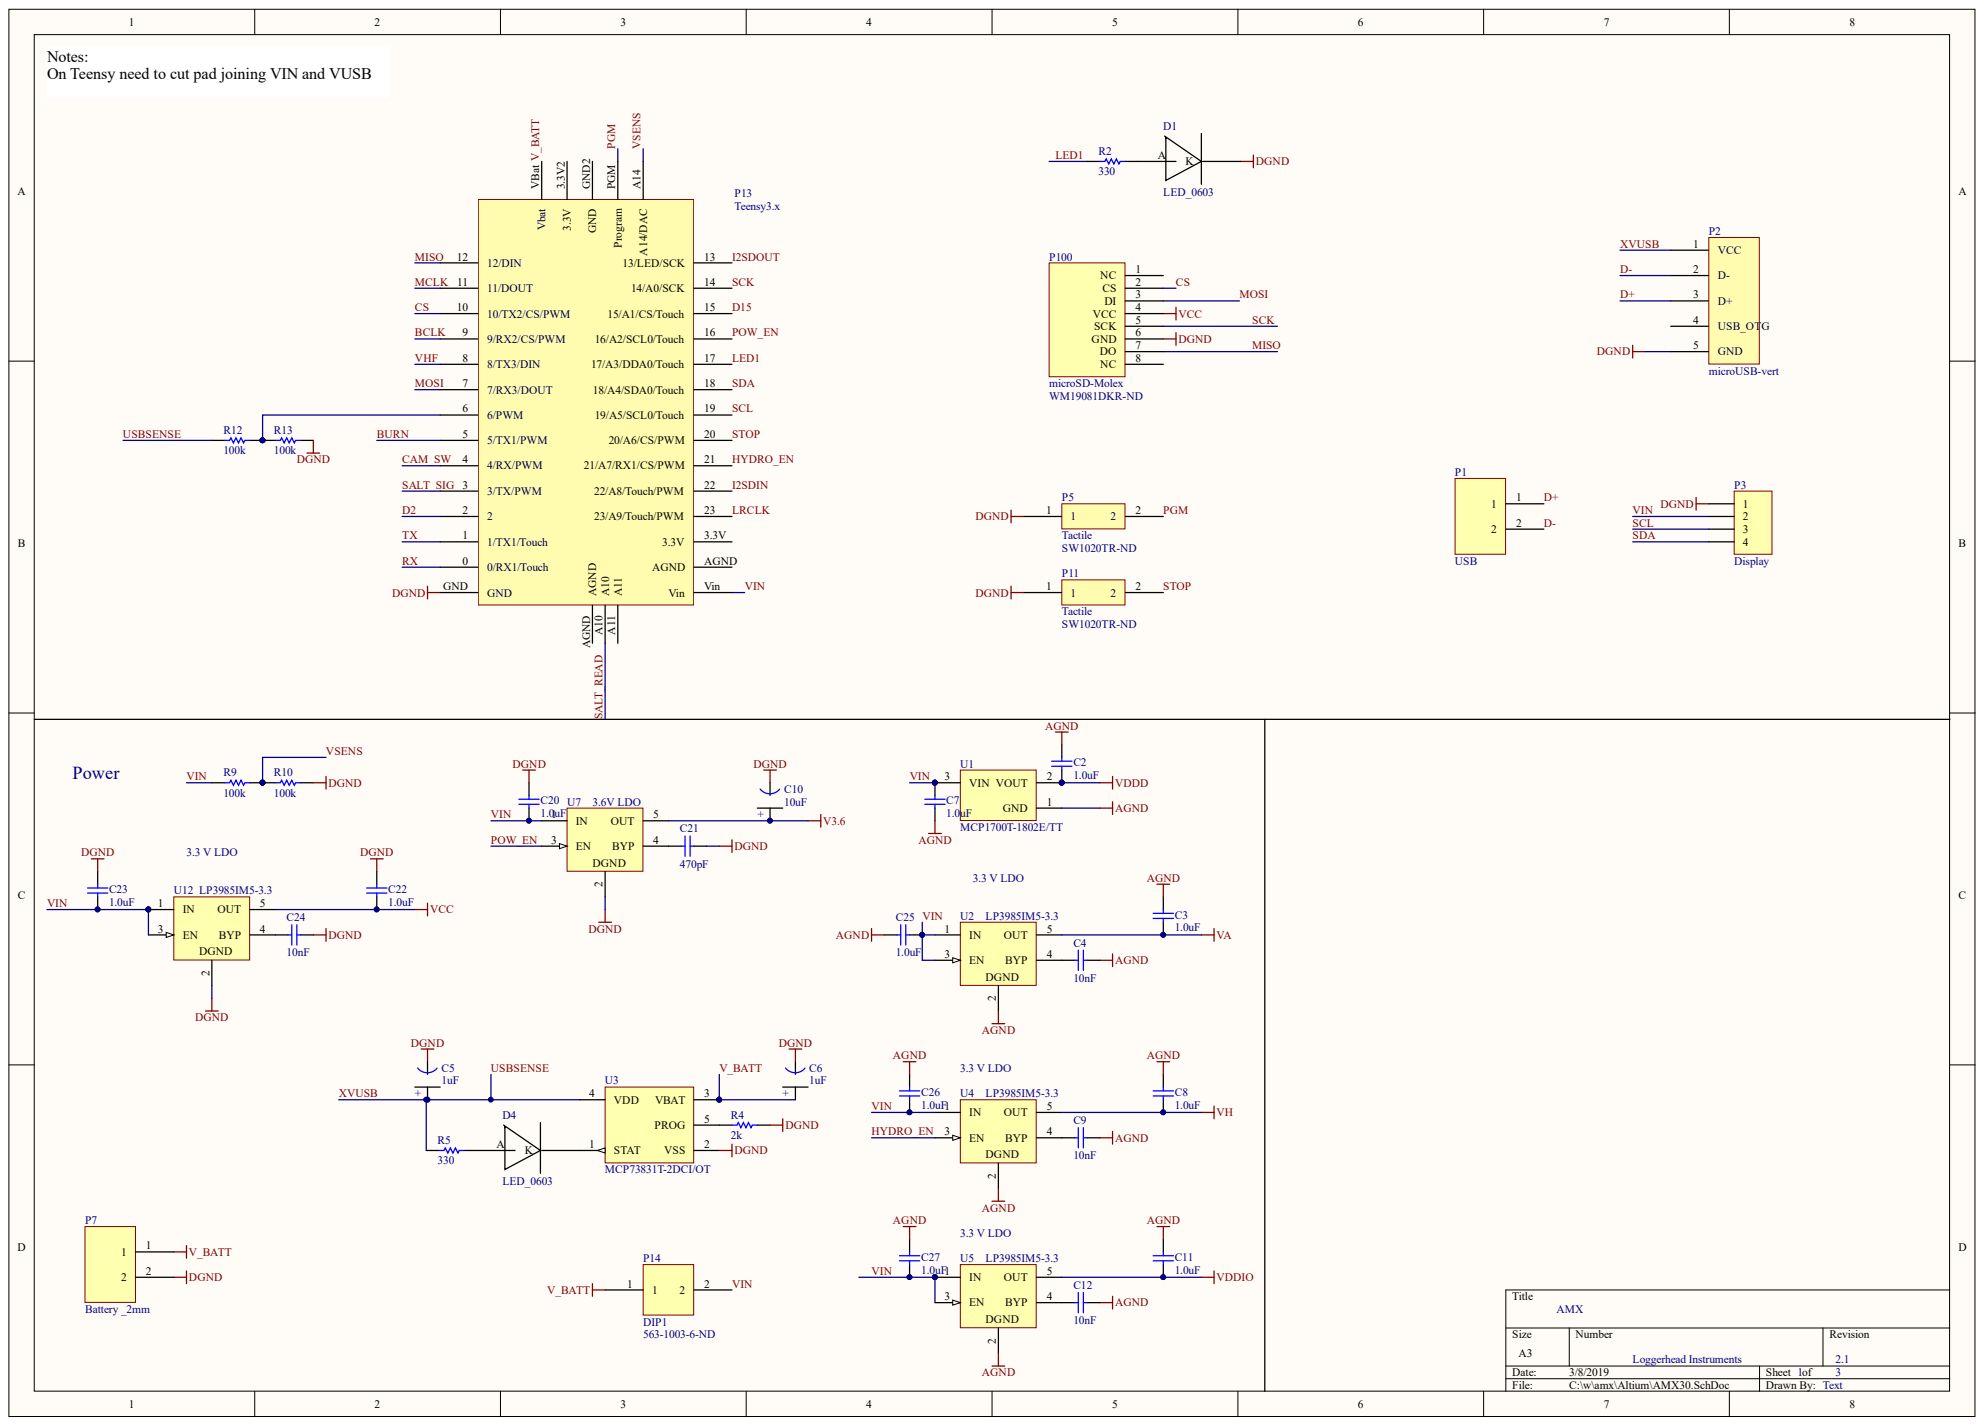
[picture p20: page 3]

Notes:
On Teensy need to cut pad joining VIN and VUSB

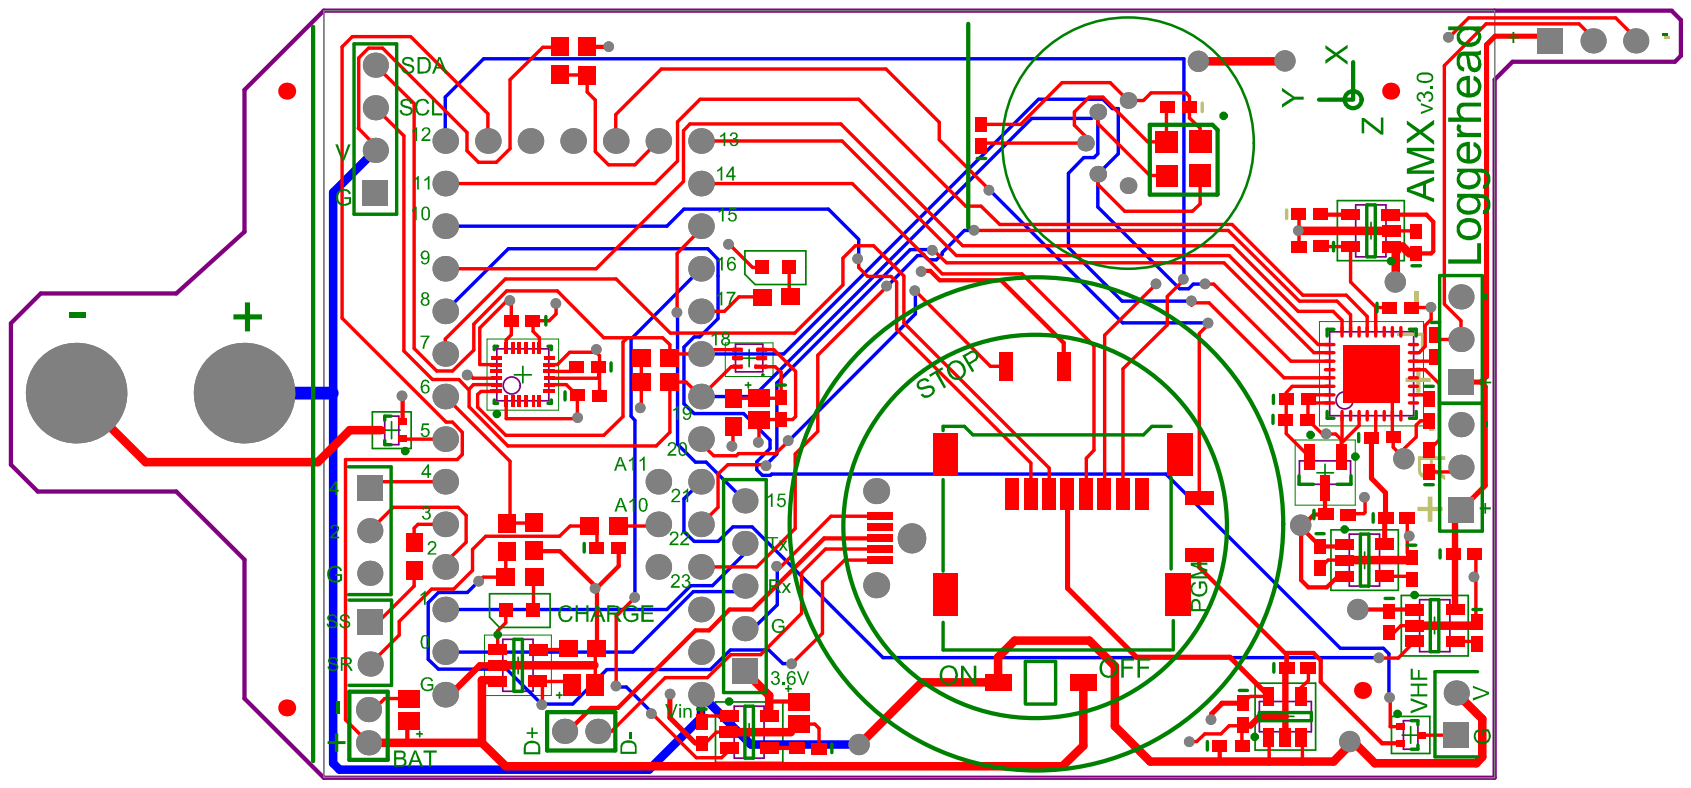
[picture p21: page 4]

Comment | Description | Designator | Footprint | LibRef | Quantity
1.0uF | Ceramic Chip Capacitor -Standard | C1, C2, C3, C7, C8, C11, C14, C15, C20, C22, C23, C25, C26, C27 | 0402 | C0402 | 14
10nF | Ceramic Chip Capacitor -Standard | C4, C9, C12, C24, C30 | 0402 | C0402 | 5
1uF | | C5, C6, C32 | Tant0805 | Tant0805 | 3
10uF | | C10 | Tant0805 | Tant0805 | 1
0.1uF | Ceramic Chip Capacitor -Standard | C13, C16, C17, C18, C19, C29, C31, C33, C34 | 0402 | C0402 | 9
470pF | Ceramic Chip Capacitor -Standard | C21 | 0402 | C0402 | 1
LED_0603 | | D1, D4 | Diode0603 | LED_0603 | 2
USB | Charging Connector | P1 | HDR_2x1_2mm | HDR_2x1_2mm | 1
microUSB-vert | Molex 105133-0011 | P2 | MICROUSB-VERT | microUSB-vert | 1
Display | Header, 4-Pin | P3 | HDR1X4 | Header 4 | 1
Burn | | P4 | BURN | Burn Screw | 1
Tactile | | P5, P11 | Tactile-B3U-1000 | Tactile_B3U-1000 | 2
VHF Power | Header, 2-Pin | P6 | HDR1X2 | Header 2 | 1
Battery _2mm | Charging Connector | P7 | HDR_2x1_2mm | HDR_2x1_2mm | 1
Salt Switch | Header, 2-Pin | P8 | HDR1X2 | Header 2 | 1
HYDROPHONE | Header, 3-Pin | P9, P10, P16 | HDR1X3 | Header 3 | 3
Header 3 | Header, 3-Pin | P12 | HDR1X3 | Header 3 | 1
Teensy3.x | | P13 | Teensy3.x | Teensy3.x | 1
DIP1 | | P14 | DIP1 | DIP1 | 1
Header 5 | Header, 5-Pin | P15 | HDR1X5 | Header 5 | 1
microSD-Molex | | P100 | microSD_Molex_hinged | microSD_Molex_hinged | 1
DMN5L06TK-7 | Ultra-low leakage Enhanced MOSFET | Q1, Q2 | SOT-523 | FET DMN5L06TK-7 | 2
100x | Precision Thick Film Chip Resistor, 10 Ohm to 1M Ohm Range, 1% and 0.5% Tolerance, 0603 Size, 0.063 W | R1 | 3-0603 | ERJ3RK | 1
330 | Precision Thick Film Chip Resistor, 10 Ohm to 1M Ohm Range, 1% and 0.5% Tolerance, 0603 Size, 0.063 W | R2, R5 | 3-0603 | ERJ3RK | 2
2k | Precision Thick Film Chip Resistor, 10 Ohm to 1M Ohm Range, 1% and 0.5% Tolerance, 0603 Size, 0.063 W | R4 | 3-0603 | ERJ3RK | 1
4.7k | Precision Thick Film Chip Resistor, 10 Ohm to 1M Ohm Range, 1% and 0.5% Tolerance, 0603 Size, 0.063 W | R6, R7 | 3-0603 | ERJ3RK | 2
100k | Precision Thick Film Chip Resistor, 10 Ohm to 1M Ohm Range, 1% and 0.5% Tolerance, 0603 Size, 0.063 W | R9, R10, R12, R13 | 3-0603 | ERJ3RK | 4
10k | Precision Thick Film Chip Resistor, 10 Ohm to 1M Ohm Range, 1% and 0.5% Tolerance, 0603 Size, 0.063 W | R18 | 3-0603 | ERJ3RK | 1
1k | Precision Thick Film Chip Resistor, 10 Ohm to 1M Ohm Range, 1% and 0.5% Tolerance, 0603 Size, 0.063 W | R19 | 3-0603 | ERJ3RK | 1
MCP1700T-1802E/TT | Low Quiescent Current LDO, 3-Pin SOT-23, Extended Temperature, Tape and Reel | U1 | SOT-23-TT3_N | MCP1700T-1802E/TT | 1
LP3985IM5-3.3 | Micropower, 150mA Low-Noise Ultra Low-Dropout CMOS Voltage Regulator | U2, U4, U5, U12 | MF05A_N | LP3985IM5-3.3 | 4
MCP73831T-2DCI/OT | Miniature Single-Cell, Fully Integrated Li-Ion, Li-Polymer Charge Management Controller, 4.2V, 5-Pin SOT-23, Industrial Temperature, Tape and Reel | U3 | SOT-23-OT5_N | MCP73831T-2DCI/OT | 1
SGTL5000 | SGTL5000 | U6 | QFN32 | SGTL5000 | 1
3.6V LDO | Micropower, 150mA Low-Noise Ultra Low-Dropout CMOS Voltage Regulator | U7 | MF05A_N | LP3985IM5-3.3 | 1
MPU9250 | Invensense | U8 | MPU6500 | MPU-9250 | 1
Keller7LD | Keller Pressure/Temp | U9 | Keller7LD | Keller 7LD | 1
MS5837 | Pressure/Temp | U10 | MS5837 | MS5837 | 1
RGB light | RGB light sensor | U11 | ODFN | ISL29125 | 1

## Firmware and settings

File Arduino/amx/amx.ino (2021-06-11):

//
// AMX--Audio, Motion, Light, Pressure datalogger
//
// Loggerhead Instruments
// 2016
// David Mann
// 
// Modified from PJRC audio code
// http://www.pjrc.com/store/teensy3_audio.html
//
// Loggerhead AMX board is required for accelerometer, mageter, gyroscope, RGB light, pressure, and temperature sensors
//

// Note: Need to change Pressure/Temperature coefficient for MS5801 1 Bar versus 30 Bar sensor
// Compile 72 MHz Fastest


#include <Audio.h>  //this also includes SD.h from lines 89 & 90
#include <analyze_fft256.h>
#include <Wire.h>
//#include <i2c_t3.h>  //https://github.com/nox771/i2c_t3
#include <SPI.h>
//#include <SdFat.h>
#include "amx32.h"
#include <Snooze.h>  //using https://github.com/duff2013/Snooze; uncomment line 62 #define USE_HIBERNATE
#include <TimeLib.h>
#include <Adafruit_GFX.h>
#include <Adafruit_SSD1306.h> // modify so calls i2c_t3 not Wire.h
#include <Adafruit_FeatherOLED.h>
#include <EEPROM.h>
#include <TimerOne.h>

#define CPU_RESTART_ADDR (uint32_t *)0xE000ED0C
#define CPU_RESTART_VAL 0x5FA0004
#define CPU_RESTART (*CPU_RESTART_ADDR = CPU_RESTART_VAL);

#define OLED_RESET -1

#define displayLine1 0
#define displayLine2 8
#define displayLine3 16
#define displayLine4 25
Adafruit_FeatherOLED display = Adafruit_FeatherOLED();
#define BOTTOM 25

// set this to the hardware serial port you wish to use
#define HWSERIAL Serial1  // Rx: 0; Tx: 1

#define SPYCAM 1
#define FLYCAM 2

// Select which MS58xx sensor is used on board to correctly calculate pressure in mBar
#define MS5837_30bar

#ifdef MS5837_02bar
  #define MS58xx_constant 327680.0
  #define pressAddress 0x76
#endif
#ifdef MS5837_30bar
  #define MS58xx_constant 8192.0
  #define pressAddress 0x76
#endif

// 
// Dev settings
//
static int printDiags = 1;  // 1: serial print diagnostics; 0: no diagnostics 2=verbose
int dd = 1; //display on
long rec_dur = 3600; // seconds;
long rec_int = 0;
unsigned int delayStartMinutes = 0;
unsigned int delayStartHours = 0;
boolean hallFlag = 0;

int nPlayBackFiles = 0; // number of playback files
int minPlayBackInterval = 120; // keep playbacks from being closer than x seconds
int longestPlayback = 30; // longest file for playback, used to power down playback board
float playBackDepthThreshold = 10.0; // tag must go deeper than this depth to trigger threshold
float ascentDepthTrigger = 5.0; // after exceed playBackDepthThreshold, must ascend this amount to trigger playback
float playBackResetDepth = 2.0; // tag needs to come back above this depth before next playback can happen
int maxPlayBacks = 20; // maximum number of times to play

int simulateDepth = 0;
float depthProfile[] = {0.0, 12.0, 1.0, 12.0, 4.0, 3.0, 10.0, 20.0, 50.0, 10.0, 0.0, 1.0, 40.0, 11.0, 5.0, 2.0, 0.0, 50.0, 2.0, 4.0,
                      0.0, 12.0, 1.0, 20.0, 4.0, 3.0, 10.0, 20.0, 50.0, 10.0, 0.0, 1.0, 12.0, 11.0, 5.0, 2.0, 0.0, 60.0, 2.0, 4.0,
                      0.0, 12.0, 1.0, 20.0, 4.0, 3.0, 10.0, 20.0, 50.0, 10.0, 0.0, 1.0, 12.0, 11.0, 5.0, 2.0, 0.0, 70.0, 2.0, 4.0}; //simulated depth profile; one value per minute


int camType = SPYCAM; // when on continuously cameras make a new file every 10 minutes

int camFlag = 0;
boolean camWave = 0; // one flag to swtich all settings to use camera control and wav files (camWave = 1)

float max_cam_hours_rec = 10.0; // turn off camera after max_cam_hours_rec to save power; SPYCAM gets ~10 hours with 32 GB card--depends on compression
byte fileType = 1; //0=wav, 1=amx
int moduloSeconds = 60; // round to nearest start time

float depthThreshold = 1.0; //depth threshold is given as a positive depth (e.g. 2: if depth < 2 m VHF will go on)
int saltThreshold = 10; // if voltage difference with digital out ON - digital out OFF is less than this turn off LED
//
//

static uint8_t myID[8];

unsigned long baud = 115200;

#define SECONDS_IN_MINUTE 60
#define SECONDS_IN_HOUR 3600
#define SECONDS_IN_DAY 86400
#define SECONDS_IN_YEAR 31536000
#define SECONDS_IN_LEAP 31622400

#define MODE_NORMAL 0
#define MODE_DIEL 1

// GUItool: begin automatically generated code
AudioInputI2S            i2s2;           //xy=105,63
AudioAnalyzeFFT256       fft256_1; 
AudioRecordQueue         queue1;         //xy=281,63
AudioConnection          patchCord1(i2s2, 0, queue1, 0);
AudioConnection          patchCord2(i2s2, 0, fft256_1, 0);
AudioControlSGTL5000     sgtl5000_1;     //xy=265,212
// GUItool: end automatically generated code

const int myInput = AUDIO_INPUT_LINEIN;
float gainDb;
float hydroCal = -180;
int noDC = 0; // 0 = freezeDC offset; 1 = remove DC offset

// Pin Assignments
#define CAM_TRIG 4
#define hydroPowPin 21
#define VHF 8
#define displayPow 20
#define SALT A11
#define saltSIG 3
#define ledGreen 17
#define BURN 5
#define usbSense 6
#define vSense A14  // moved to Pin 21 for X1
#define PLAY_POW 16
#define STOP 20
#define HALL 2

// Pins used by audio shield
// https://www.pjrc.com/store/teensy3_audio.html
// MEMCS 6
// MOSI 7
// BCLK 9
// SDCS 10
// MCLK 11
// MISO 12
// RX 13
// SCLK 14
// VOL 15
// SDA 18
// SCL 19
// TX 22
// LRCLK 23

// Remember which amxMode we're doing
int amxMode = 0;  // 0=stopped, 1=recording, 2=playing
time_t startTime;
time_t stopTime;
time_t t;
time_t burnTime;
time_t playTime;
byte startHour, startMinute, endHour, endMinute; //used in Diel mode

boolean imuFlag = 1;
boolean rgbFlag = 1;
int burnFlag = 0; // set by setup.txt file if use BW or BM
byte pressure_sensor = 0; //0=none, 1=MS5802, 2=Keller PA7LD; autorecognized 
boolean audioFlag = 1;
boolean CAMON = 0;

boolean briteFlag = 0; // bright LED
long burnMinutes = 0;
int burnLog = 0; //burn status for log file

volatile boolean LEDSON = 1;
boolean introperiod=1;  //flag for introductory period; used for keeping LED on for a little while

int update_rate = 100;  // rate (Hz) at which interrupt to read RGB and P/T sensors will run, so sensor_srate needs to <= update_rate
float sensor_srate = 1.0;
float imu_srate = 100.0;
float audio_srate = 44100.0;

int accel_scale = 16; //full scale on accelerometer [2, 4, 8, 16] (example cmd code: AS 8)


// Playback
int playNow = 0;
int trackNumber = 0;
int playBackDepthExceeded = 0;
float maxDepth;  
int nPlayed = 0;

float audioIntervalSec = 256.0 / audio_srate; //buffer interval in seconds
unsigned int audioIntervalCount = 0;
int systemGain = 4; // SG in script file

int recMode = MODE_NORMAL;

int wakeahead = 20;  //wake from snooze to give hydrophone and camera time to power up
int snooze_hour;
int snooze_minute;
int snooze_second;
volatile long buf_count;
float total_hour_recorded = 0.0;
long nbufs_per_file;
boolean settingsChanged = 0;

long file_count;
char filename[25];
char dirname[8];
int folderMonth;
//SnoozeBlock snooze_config;
SnoozeAlarm alarm;
SnoozeAudio snooze_audio;
SnoozeBlock config_teensy32(snooze_audio, alarm);

// The file where data is recorded
File frec;

typedef struct {
    char    rId[4];
    unsigned int rLen;
    char    wId[4];
    char    fId[4];
    unsigned int    fLen;
    unsigned short nFormatTag;
    unsigned short nChannels;
    unsigned int nSamplesPerSec;
    unsigned int nAvgBytesPerSec;
    unsigned short nBlockAlign;
    unsigned short  nBitsPerSamples;
    char    dId[4];
    unsigned int    dLen;
} HdrStruct;

HdrStruct wav_hdr;
unsigned int rms;

// Header for amx files
DF_HEAD dfh;
SID_SPEC sidSpec[SID_MAX];
SID_REC sidRec[SID_MAX];
SENSOR sensor[SENSOR_MAX]; //structure to hold sensor specifications. e.g. MPU9250, MS5803, PA47LD, ISL29125

unsigned char prev_dtr = 0;

// IMU
int FIFOpts;
#define IMUBUFFERSIZE 1800 // used this length because it is divisible by 18 bytes (e.g. A*3,M*3,G*3);
volatile byte imuBuffer[IMUBUFFERSIZE]; // buffer used to store IMU sensor data before writes in bytes
volatile byte time2writeIMU=0; 
volatile int IMUCounter = 0;
volatile int bufferposIMU = 0;
int halfbufIMU = IMUBUFFERSIZE/2;
volatile boolean firstwrittenIMU;
volatile uint8_t imuTempBuffer[20];
int16_t accel_x;
int16_t accel_y;
int16_t accel_z;
int16_t mag_x;
int16_t mag_y;
int16_t mag_z;
int16_t gyro_x;
int16_t gyro_y;
int16_t gyro_z;
float gyro_temp;
int magXoffset;
int magYoffset;
int magZoffset;
float pitch, roll, yaw;

// RGB
int16_t islRed;
int16_t islBlue;
int16_t islGreen;

// Pressure/Temp
byte Tbuff[3];
byte Pbuff[3];
volatile float pressure_mbar, temperature, depth, pressureOffset_mbar;
volatile boolean togglePress; //flag to toggle conversion of pressure and temperature

//Pressure and temp calibration coefficients
uint16_t PSENS; //pressure sensitivity C1
uint16_t POFF;  //Pressure offset C2
uint16_t TCSENS; //Temp coefficient of pressure sensitivity C3
uint16_t TCOFF; //Temp coefficient of pressure offset C4
uint16_t TREF;  //Ref temperature C5
uint16_t TEMPSENS; //Temperature sensitivity coefficient C6

// Pressure, Temp double buffer
#define PTBUFFERSIZE 40
volatile float PTbuffer[PTBUFFERSIZE];
volatile byte time2writePT = 0; 
volatile int ptCounter = 0;
volatile byte bufferposPT=0;
byte halfbufPT = PTBUFFERSIZE/2;
volatile boolean firstwrittenPT;

// RGB buffer
#define RGBBUFFERSIZE 120
volatile byte RGBbuffer[RGBBUFFERSIZE];
volatile byte time2writeRGB=0; 
volatile int RGBCounter = 0;
volatile byte bufferposRGB=0;
byte halfbufRGB = RGBBUFFERSIZE/2;
volatile boolean firstwrittenRGB;

// impeller spin counter
volatile int spin;

#define HWSERIAL Serial1

IntervalTimer slaveTimer;

void setup() {
  dfh.Version = 20200628; //unsigned long
  dfh.UserID = 5555;

  if (camWave){
    imuFlag = 0;
    rgbFlag = 0;
    audioFlag = 1;
    camFlag = 1;
    briteFlag = 1;
    fileType = 0; // 0 = wav
  }

  read_myID();
  
  Serial.begin(baud);
  HWSERIAL.begin(9600); //playback

  RTC_CR = 0; // disable RTC
  delay(100);
  Serial.println(RTC_CR,HEX);
  // change capacitance to 26 pF (12.5 pF load capacitance)
  RTC_CR = RTC_CR_SC16P | RTC_CR_SC8P | RTC_CR_SC2P; 
  delay(100);
  RTC_CR = RTC_CR_SC16P | RTC_CR_SC8P | RTC_CR_SC2P | RTC_CR_OSCE;
  delay(100);

  delay(500);
  Wire.begin();
  //Wire.begin(I2C_MASTER, 0x00, I2C_PINS_18_19, I2C_PULLUP_EXT, I2C_RATE_400);
 // Wire.setDefaultTimeout(10000);

  displayOn();
  cDisplay();
  display.println("Loggerhead");
  display.display();

  // Initialize the SD card
  SPI.setMOSI(7);
  SPI.setSCK(14);
  if (!(SD.begin(10))) {
    // stop here if no SD card, but print a message
    Serial.println("Unable to access the SD card");
    
    while (1) {
      cDisplay();
      display.println("SD error");
      display.display();
      for (int flashMe=0; flashMe<3; flashMe++){
      delay(100);
      digitalWrite(ledGreen, HIGH);
      delay(100);
      digitalWrite(ledGreen, LOW);
      }
      delay(400);
    }
  }

  LoadScript();
 
  sensorInit(); // initialize and test sensors
  logFileHeader();
  setGain();

  if(printDiags > 0){
      Serial.print("YY-MM-DD HH:MM:SS ");
      // show 3 ticks to know crystal is working
      for (int n=0; n<3; n++){
        printTime(getTeensy3Time());
        delay(1000);
      }
   }

  pinMode(usbSense, OUTPUT);
  digitalWrite(usbSense, LOW); // make sure no pull-up
  pinMode(usbSense, INPUT);
  delay(500);    

  Serial.println("Loggerhead");
  //display.println("USB <->");
  //display.display();
  // Check for external USB connection to microSD
  digitalWrite(ledGreen, HIGH);
  digitalWrite(hydroPowPin, HIGH);

  if(!printDiags){ 
   while(digitalRead(usbSense)){
      pinMode(usbSense, OUTPUT);
      digitalWrite(usbSense, LOW); // forces low if USB power pulled
      pinMode(usbSense, INPUT);
      delay(500);

      // allow use of stop button to get out of this loop
      if(digitalRead(STOP)==0){
        delay(10); // simple deBounce
        if(digitalRead(STOP)==0) break;
      }
    }
  }

  
  setSyncProvider(getTeensy3Time); //use Teensy RTC to keep time


// ULONG newtime;
 
  // Power down USB if not using Serial monitor
  if (printDiags==0){
    //  usbDisable();
  }
  
//
//  cDisplay();
//  display.println("Loggerhead");
//  display.display();
  
 
  //SdFile::dateTimeCallback(file_date_time);

  
  mpuInit(1);; // update MPU with new settings
  setupDataStructures();

  //cDisplay();

  t = getTeensy3Time();

  if(burnFlag==2){
    burnTime = t + (burnMinutes * 60);
  }

  long delayStartSeconds = (60 * delayStartMinutes) + (3600 * delayStartHours);
  startTime = t + delayStartSeconds;
  if(delayStartSeconds == 0){
    startTime = t + 10; // make sure have at least 10 seconds
    startTime -= startTime % moduloSeconds;  //modulo to nearest 60 seconds
    startTime += moduloSeconds; //move forward
  }

  stopTime = startTime + rec_dur;  // this will be set on start of recording
  
  if (recMode==MODE_DIEL) checkDielTime();  
  
  nbufs_per_file = (long) (rec_dur * audio_srate / 256.0);
  
  long ss = rec_int - wakeahead;
  if (ss<0) ss=0;
  snooze_hour = floor(ss/3600);
  ss -= snooze_hour * 3600;
  snooze_minute = floor(ss/60);
  ss -= snooze_minute * 60;
  snooze_second = ss;
  Serial.print("Snooze HH MM SS ");
  Serial.print(snooze_hour);
  Serial.print(snooze_minute);
  Serial.println(snooze_second);

  Serial.print("rec dur ");
  Serial.println(rec_dur);
  Serial.print("rec int ");
  Serial.println(rec_int);
  Serial.print("Current Time: ");
  printTime(t);
  Serial.print("Start Time: ");
  printTime(startTime);
  
  // Sleep here if won't start for 120 s
  long time_to_first_rec = startTime - t;
  Serial.print("Time to first record ");
  Serial.println(time_to_first_rec);
  for(int x = 0; x<5; x++){
    cDisplay();
    t = getTeensy3Time();
    display.println("Sleep until:");
    displayClock(14, startTime);
    displayClock(BOTTOM, t);
    display.display();
    delay(1000);
  }


  if(time_to_first_rec>120){
    // power things off
    digitalWrite(hydroPowPin, LOW);
    audio_power_down();
    playOff(); // power down playback board
    mpuInit(0); // sleep MPU
    islSleep(); // RGB light sensor
    
    while(time_to_first_rec > 60){
      displayOff();
      
      digitalWrite(ledGreen, HIGH);
      alarm.setRtcTimer(0, 0, 20); // sleep 20 seconds
      delay(10);
      digitalWrite(ledGreen, LOW);
      
      Snooze.sleep(config_teensy32);
      //Snooze.deepSleep( config_teensy32 );
      /// .... sleeping ...
      
      t = getTeensy3Time();
      time_to_first_rec = startTime - t;
    }

    mpuInit(1); // start MPU
    islInit();
    audio_power_up(); // audio chip on
  }


  displayOn();

  // Audio connections require memory, and the record queue
  // uses this memory to buffer incoming audio.
  AudioMemory(100);
  AudioInit(); // this calls Wire.begin() in control_sgtl5000.cpp
 // fft256_1.averageTogether(160); // number of FFTs to average together
  
  digitalWrite(hydroPowPin, HIGH);
  if (camFlag) cam_wake();
  amxMode = 0;

  // create first folder to hold data
  folderMonth = -1;  //set to -1 so when first file made will create directory
  
  //if (fileType) Timer1.initialize(1000000 / update_rate); // initialize with 100 ms period when update_rate = 10 Hz
  
}

//
// MAIN LOOP
//

int recLoopCount;  //for debugging when does not start record

void loop() {
  // if plug in USB power--get out of main loop
  if(!printDiags){
    if (digitalRead(usbSense)){  
        if (amxMode==1) stopRecording();
        resetFunc();
      }
  }

  t = getTeensy3Time();
  if((t >= burnTime) & (burnFlag>0)){
     digitalWrite(BURN, HIGH);  // burn on
     digitalWrite(VHF, HIGH);   // VHF on
     digitalWrite(ledGreen, LOW);
     burnLog = 1;

    // if burning and voltage is low; stop recording
     if(readVoltage() < 3.6){  
       if (amxMode == 1) stopRecording();
       if (camFlag) {
        cam_stop();
        delay(100);
       }
       frec.close();
       audio_power_down();
       digitalWrite(hydroPowPin, LOW); //hydrophone off
       playOff(); // power down playback board
        
       while(1){
          alarm.setRtcTimer(0, 2, 0);  // sleep for 2 minutes
          Snooze.sleep(config_teensy32);
  
          // ... asleep ...
          for(int n = 0; n<10; n++){
            digitalWrite(ledGreen, HIGH);
            delay(200);
            digitalWrite(ledGreen, LOW);
            delay(100);
          }
       }
     }
  }
  
  // Standby mode
  if(amxMode == 0)
  {
      if(dd){
        cDisplay();
        displaySettings();
        displayClock(BOTTOM, t);
        display.display();
      }
      
      if((t >= startTime - 4) & CAMON==1 & (camType==SPYCAM)){ //start camera 4 seconds before to give a chance to get going
        if (camFlag)  cam_start();
      }
      if(t >= startTime){      // time to start?
        Serial.println("Record Start.");
        cDisplay();
        display.display();

        if(noDC==0) {
          audio_freeze_adc_hp(); // this will lower the DC offset voltage, and reduce noise
          noDC = -1;
        }
        
        stopTime = startTime + rec_dur;
        startTime = stopTime + rec_int;
        if (recMode==MODE_DIEL) checkDielTime();

        Serial.print("Current Time: ");
        printTime(getTeensy3Time());
        Serial.print("Stop Time: ");
        printTime(stopTime);
        Serial.print("Next Start:");
        printTime(startTime);

        //convert pressure and temperature for first reading
        updateTemp();
        displayOff();

        amxMode = 1;      
        if(hallFlag) attachInterrupt(HALL, spinCount, RISING);      
        startRecording();
      }
      delay(100);
  }


  // Record mode
  if (amxMode == 1) {
    continueRecording();  // download data  

    // Check if stop button pressed
    if(digitalRead(STOP)==0){
      delay(10); // simple deBounce
      if(digitalRead(STOP)==0){
        stopRecording();
        digitalWrite(ledGreen, HIGH);
        if(dd){
          displayOn();
          delay(1000);
          cDisplay();
          display.println("Stopped");
          display.println();
          display.print("Safe to turn off");
          display.display();
        }
        delay(58000); // if don't power off in 60s, restart
        if(dd){
          cDisplay();
          display.print("Restarting");
          display.display();
          delay(2000);
          displayOff();
        }
        FileInit();
        digitalWrite(ledGreen, LOW);
      }
    }
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

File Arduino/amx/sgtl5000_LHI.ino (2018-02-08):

#include "control_sgtl5000.h"

#define SGTL5000_I2C_ADDR  0x0A  // CTRL_ADR0_CS pin low (normal configuration)

#define CHIP_ID        0x0000
// 15:8 PARTID    0xA0 - 8 bit identifier for SGTL5000
// 7:0  REVID   0x00 - revision number for SGTL5000.

#define CHIP_DIG_POWER      0x0002
// 6  ADC_POWERUP 1=Enable, 0=disable the ADC block, both digital & analog, 
// 5  DAC_POWERUP 1=Enable, 0=disable the DAC block, both analog and digital
// 4  DAP_POWERUP 1=Enable, 0=disable the DAP block
// 1  I2S_OUT_POWERUP 1=Enable, 0=disable the I2S data output
// 0  I2S_IN_POWERUP  1=Enable, 0=disable the I2S data input

#define CHIP_CLK_CTRL     0x0004
// 5:4  RATE_MODE Sets the sample rate mode. MCLK_FREQ is still specified
//      relative to the rate in SYS_FS
//        0x0 = SYS_FS specifies the rate
//        0x1 = Rate is 1/2 of the SYS_FS rate
//        0x2 = Rate is 1/4 of the SYS_FS rate
//        0x3 = Rate is 1/6 of the SYS_FS rate
// 3:2  SYS_FS    Sets the internal system sample rate (default=2)
//        0x0 = 32 kHz
//        0x1 = 44.1 kHz
//        0x2 = 48 kHz
//        0x3 = 96 kHz
// 1:0  MCLK_FREQ Identifies incoming SYS_MCLK frequency and if the PLL should be used
//        0x0 = 256*Fs
//        0x1 = 384*Fs
//        0x2 = 512*Fs
//        0x3 = Use PLL
//        The 0x3 (Use PLL) setting must be used if the SYS_MCLK is not
//        a standard multiple of Fs (256, 384, or 512). This setting can
//        also be used if SYS_MCLK is a standard multiple of Fs.
//        Before this field is set to 0x3 (Use PLL), the PLL must be
//        powered up by setting CHIP_ANA_POWER->PLL_POWERUP and
//        CHIP_ANA_POWER->VCOAMP_POWERUP.  Also, the PLL dividers must
//        be calculated based on the external MCLK rate and
//        CHIP_PLL_CTRL register must be set (see CHIP_PLL_CTRL register
//        description details on how to calculate the divisors).

#define CHIP_I2S_CTRL     0x0006
// 8  SCLKFREQ  Sets frequency of I2S_SCLK when in master mode (MS=1). When in slave
//      mode (MS=0), this field must be set appropriately to match SCLK input
//      rate.
//        0x0 = 64Fs
//        0x1 = 32Fs - Not supported for RJ mode (I2S_MODE = 1)
// 7  MS    Configures master or slave of I2S_LRCLK and I2S_SCLK.
//        0x0 = Slave: I2S_LRCLK an I2S_SCLK are inputs
//        0x1 = Master: I2S_LRCLK and I2S_SCLK are outputs
//        NOTE: If the PLL is used (CHIP_CLK_CTRL->MCLK_FREQ==0x3),
//        the SGTL5000 must be a master of the I2S port (MS==1)
// 6  SCLK_INV  Sets the edge that data (input and output) is clocked in on for I2S_SCLK
//        0x0 = data is valid on rising edge of I2S_SCLK
//        0x1 = data is valid on falling edge of I2S_SCLK
// 5:4  DLEN    I2S data length (default=1)
//        0x0 = 32 bits (only valid when SCLKFREQ=0),
//          not valid for Right Justified Mode
//        0x1 = 24 bits (only valid when SCLKFREQ=0)
//        0x2 = 20 bits
//        0x3 = 16 bits
// 3:2  I2S_MODE  Sets the mode for the I2S port
//        0x0 = I2S mode or Left Justified (Use LRALIGN to select)
//        0x1 = Right Justified Mode
//        0x2 = PCM Format A/B
//        0x3 = RESERVED
// 1  LRALIGN   I2S_LRCLK Alignment to data word. Not used for Right Justified mode
//        0x0 = Data word starts 1 I2S_SCLK delay after I2S_LRCLK
//          transition (I2S format, PCM format A)
//        0x1 = Data word starts after I2S_LRCLK transition (left
//          justified format, PCM format B)
// 0  LRPOL   I2S_LRCLK Polarity when data is presented.
//        0x0 = I2S_LRCLK = 0 - Left, 1 - Right
//        1x0 = I2S_LRCLK = 0 - Right, 1 - Left
//        The left subframe should be presented first regardless of
//        the setting of LRPOL.

#define CHIP_SSS_CTRL     0x000A
// 14 DAP_MIX_LRSWAP  DAP Mixer Input Swap
//        0x0 = Normal Operation
//        0x1 = Left and Right channels for the DAP MIXER Input are swapped.
// 13 DAP_LRSWAP  DAP Mixer Input Swap
//        0x0 = Normal Operation
//        0x1 = Left and Right channels for the DAP Input are swapped
// 12 DAC_LRSWAP  DAC Input Swap
//        0x0 = Normal Operation
//        0x1 = Left and Right channels for the DAC are swapped
// 10 I2S_LRSWAP  I2S_DOUT Swap
//        0x0 = Normal Operation
//        0x1 = Left and Right channels for the I2S_DOUT are swapped
// 9:8  DAP_MIX_SELECT  Select data source for DAP mixer
//        0x0 = ADC
//        0x1 = I2S_IN
//        0x2 = Reserved
//        0x3 = Reserved
// 7:6  DAP_SELECT  Select data source for DAP
//        0x0 = ADC
//        0x1 = I2S_IN
//        0x2 = Reserved
//        0x3 = Reserved
// 5:4  DAC_SELECT  Select data source for DAC (default=1)
//        0x0 = ADC
//        0x1 = I2S_IN
//        0x2 = Reserved
//        0x3 = DAP
// 1:0  I2S_SELECT  Select data source for I2S_DOUT
//        0x0 = ADC
//        0x1 = I2S_IN
//        0x2 = Reserved
//        0x3 = DAP

#define CHIP_ADCDAC_CTRL    0x000E
// 13 VOL_BUSY_DAC_RIGHT Volume Busy DAC Right
//        0x0 = Ready
//        0x1 = Busy - This indicates the channel has not reached its
//          programmed volume/mute level
// 12 VOL_BUSY_DAC_LEFT  Volume Busy DAC Left
//        0x0 = Ready
//        0x1 = Busy - This indicates the channel has not reached its
//          programmed volume/mute level
// 9  VOL_RAMP_EN Volume Ramp Enable (default=1)
//        0x0 = Disables volume ramp. New volume settings take immediate
//          effect without a ramp
//        0x1 = Enables volume ramp
//        This field affects DAC_VOL. The volume ramp effects both
//        volume settings and mute When set to 1 a soft mute is enabled.
// 8  VOL_EXPO_RAMP Exponential Volume Ramp Enable
//        0x0 = Linear ramp over top 4 volume octaves
//        0x1 = Exponential ramp over full volume range
//        This bit onlay takes effect if VOL_RAMP_EN is 1.
// 3  DAC_MUTE_RIGHT  DAC Right Mute (default=1)
//        0x0 = Unmute
//        0x1 = Muted
//        If VOL_RAMP_EN = 1, this is a soft mute.
// 2  DAC_MUTE_LEFT DAC Left Mute (default=1)
//        0x0 = Unmute
//        0x1 = Muted
//        If VOL_RAMP_EN = 1, this is a soft mute.
// 1  ADC_HPF_FREEZE  ADC High Pass Filter Freeze
//        0x0 = Normal operation
//        0x1 = Freeze the ADC high-pass filter offset register.  The
//        offset continues to be subtracted from the ADC data stream.
// 0  ADC_HPF_BYPASS  ADC High Pass Filter Bypass
//        0x0 = Normal operation
//        0x1 = Bypassed and offset not updated
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

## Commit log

2016-06-22 keller pressure sensor. direct USB download
2016-06-22 script file support. Pressure sensor selection
2016-06-25 rename IMU buffer
2016-07-26 pressure and light update outside interrupt
2016-08-03 Big-endian byte order for IMU
2016-08-03 diagnostics for IMU
2016-08-03 big endian for IMU read
2016-08-03 Burn at time in script
    [amx.ino, cmd.ino]
2016-08-09 USB powered off to save power and prevent pin from burning
    [amx.ino]
2016-08-30 battery voltage to log file and df_head
2016-09-09 low power settings for audio. fix problem with mic squeal getting on line in
    [amx.ino, sgtl5000_LHI.ino]
2016-09-11 flag for whether using camera....has long delays in starting and stopping camera)
2016-09-13 round fast scroll to 10. fixes #10
    [display.ino]
2016-09-13 first start time to nearest 5 minutes. fixes #11
    [amx.ino]
2016-09-26 V-Sense to AMX pin
2016-10-16 GPS and sensor test at beginning. Delete duplicate MS5803 pressure file
2016-10-16 print depth, temp, RGB on sensor init
2016-10-18 gps reset. fix bug with filename too short
    [amx.ino]
2016-12-02 MPU9250 store GAM, not temperature
2016-12-02 run IMU at 100 Hz
2016-12-07 removed camera from initial startup test
2016-12-07 camera wake ahead to 10 s so have enough time to wake up
2016-12-09 Switch to optimized I2C library
    Problem was the reading IMU was slowing down reads of audio buffers.
    Switched to i2c_t3 library
    https://github.com/nox771/i2c_t3
    Note: required to make modifications to other libraries (Teensy audio and Adafruit_MCP23017 I2c expander to use i2c_t3.h instead of Wire.h)
    Moved IMU read into main loop.
    Read IMU with multibyte read.
    In read audio buffer loop, buffers read until number available is <2.
    [MPU9250.ino, amx.ino, cmd.ino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]
2016-12-12 update pressure and temp fix. Save pressure mBar not depth
    [MS5803.ino, amx.ino]
2016-12-12 LED introperiod so LEDs on first file
2016-12-30 Upon power connection close open file, restart
2017-01-26 Fixed MS5803 Press calcs. Fixed GPS for Adafruit module
    [MS5803.ino, amx.ino]
2017-01-26 leave green LED on after get GPS fix
    [amx.ino]
2017-01-30 clear bad readings of pressure sensor
2017-01-30 red led if SD errro
2017-01-30 3 flash green LED for SD error
    [amx.ino]
2017-02-02 MFC should be included in installation. MFC40.dll included in zip just in case. Put in c:\windows\SysWOW64
2017-02-08 sensor spec sheets
2017-02-24 Set accelerometer range from script
2017-02-24 fix gyro lpf; add accel lpf
    [MPU9250.ino]
2017-03-03 aggressively read IMU FIFO to minimize dropped samples and shifted frames
2017-03-03 less aggressive reading of audio buffer so IMU does not overflow. Track IMU overflow to log file.
2017-03-03 unix time fix. fixes #18
    [amx.ino, cmd.ino]
2017-03-05 adjust voltage divider sensitivity
2017-03-05 change MS5803-30BA constant. Fixes #17
    [amx.ino]
2017-03-05 reset IMU FIFO if overflows before new file. Fixes #21
    [amx.ino]
2017-03-07 byte swap IMU in MATLAB
2017-03-07 Rebuilt new AMX2WAV in VS Community 2015 with static linking. Fixed byte swap issue for IMU.
2017-03-21 tone detection to trigger burn wire
    [amx.ino, cmd.ino]
2017-03-21 spy camera control
2017-03-21 updated camera trigger timing
2017-03-22 use getTeensy3Time instead of now to get time. fixes #23
    [amx.ino]
2017-03-22 when 0 s between files, let camera free run
2017-03-22 500 mA LDO to drive camera power
2017-03-23 disable camera after 8 hours recorded
2017-03-23 updated to use 300k/100k voltage divider and 1.2V Vref
2017-03-24 cleanup voltage reading
2017-03-24 power camera through GPS V so can switch off
2017-03-28 always check burn time. lite on when audio record starts
    [amx.ino]
2017-03-29 brite lite off after camera disabled
2017-04-06 amxLoad to work with AMX and iTag split out IMU and use calibration
2017-04-12 wake up camera 30s early so starts reliably
2017-04-13 fix start time issue
    [amx.ino]
2017-04-15 fix spycam files not having time to close
    [amx.ino]
2017-04-24 fix for AMX board and iTag
2017-04-26 read IMU registers directly. not using FIFO
2017-04-26 fix store updated IMU data
    [MPU9250.ino, amx.ino]
2017-04-26 fix accelerometer write
2017-04-26 fix IMU ring buffer
    [amx.ino]
2017-04-27 volatile variables for interrupt function
2017-04-27 toggle pressure and temperature reading:
2017-05-04 fix year for filename from GPS
    [amx.ino]
2017-05-24 audio setup same as LS1; hp off to lower noise
    [sgtl5000_LHI.ino]
2017-05-24 LEDs informative about status. Salt switch to control LED
2017-05-24 flash based on IMU writes. remove setting from script
2017-05-30 depth controlled VHF fixed. salt switch disabled
    [amx.ino]
2017-07-31 uart play
2017-07-31 change logic for minimum time between playbacks to prevent play back at surface
    [amx.ino]
2017-10-11 change LED to AUDIO_AMP
2017-10-11 LD: Led disable
2017-10-12 fix commenting of script TM
    [amx.ino, cmd.ino]
2017-10-24 NED orientation and calibration coefficients
2017-11-08 SerialUSB shoudl be Serial for Teensy
2017-12-18 amx Altium files
    [AMX3.PrjPCB, AMX30.SchDoc, AMX_audio30.SchDoc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]
2017-12-24 add 3.6V back for playback board
    [AMX3.PrjPCB, AMX30.SchDoc, AMX_sensors30.SchDoc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]
2017-12-28 overlay text
    [AMX_v30.PcbDoc]
2017-12-28 mechanical outline
    [AMX_v30.PcbDoc]
2018-01-11 pick and place
    [AMX3.PrjPCB, AMX_v30.PcbDoc, Pick Place for AMX_v30.csv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]
2018-01-22 fix display, add stop
    [amx.ino, display.ino]
2018-01-22 display sensor init
2018-01-22 after burn, keep recording until volts<3.6V
    [amx.ino]
2018-01-22 trim voltage divider to match voltmeter
2018-01-22 freeze ADC delay for DC offset; stgl5000 same as LS1
2018-01-22 calc and display pitch, roll, yaw
2018-01-22 MS5837 pressure sensor
2018-01-24 fix sleep bug; hydro cal and gain to SID header
    [amx.ino, cmd.ino]
2018-02-01 Keller depth, add debug cmd, adjust voltage measurement
    Adjust Keller depth calculation
    fix #28
    [PA7LD.ino, amx.ino, cmd.ino]
2018-02-06 camera manual
2018-02-07 fix keller depth sign
    Depth is positive for deeper
    [PA7LD.ino]
2018-02-08 start test playback with track 0
2018-02-08 fix from merge
    replaced cmd.ino with playback branch
    amx.ino--removed GPS bits
    [amx.ino, cmd.ino]
2018-02-14 lower interrupt priority
    Was causing issues with dropping audio chunks
    [PA7LD.ino, amx.ino]
2018-02-15 clarification of teensy loader
2018-03-14 fix delay start
    if only hour set was ignored
    [amx.ino]
2018-03-14 stop button breaks out of loop if USB plugged in
2018-03-14 lower power sleep mode
    Draws 2.6 mA in sleep when delay start.
    Draws 58 mA running.
2018-03-24 pressure offset to log file
2018-03-24 make sure green LED not stuck on
    [amx.ino]
2018-08-01 update to current libraries, export debug DF_HEAD
2018-08-01 voltage is float
2018-09-24 export CSV values
    [3D_HMS_14_15_32__DMY_10_ 8_2017.csv, LI_HMS_14_15_32__DMY_10_ 8_2017.csv]
2019-01-29 72 MHz compilation; reduce power between interrupts
2019-03-08 Schematic PCB PDF
2019-03-11 no csv for AUDIO; header based on sid_spec for sensor csv files
2019-03-11 fix pressure offset calculation
    [amx.ino]
2019-03-11 add Hall sensor, change RTC xtal capacitance
2019-03-26 Enable LED and update hex
2019-06-11 csv all in one file
    [3D_HMS_14_15_32__DMY_10_ 8_2017.csv, LI_HMS_14_15_32__DMY_10_ 8_2017.csv]
2019-06-11 datetime to 32-bit sensor csv files
2019-06-11 fix timestamp GPS and pressure
2019-12-05 euler calculation of pitch roll yaw
2019-12-18 orient axes for AMX camera
2019-12-18 unwrap yaw
2020-03-11 switch to Wire, Arduino 1.8.10
